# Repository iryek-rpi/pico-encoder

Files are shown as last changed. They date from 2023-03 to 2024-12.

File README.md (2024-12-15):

# TCP/IP packet encoder based on Raspberry Pi Pico W + W5500-EVB-Pico

* Raspberry Pi Pico W for serving a device configuration web page
* W5500-EVB-Pico from Wiznet for TCP/IP relay

## Sponsorship from PCBWay

* [PCBWay](https://www.pcbway.com/) kindly provided PCB of this device. This is my first time using the company's service.
* My honest impression is that their service is **well-streamlined with web-based ordering process** with good support of **instant chat assistance**. I could quickly make my order on the comprehensive web page.
* It took about a week to receive the assembled PCB at home in Korea. It was good to see that **each PCB was separately packaged**. The quality of the final product was excellent.
* I want to thank PCBWay again for their support. Highly recommend PCBWay. Try their excellent service at https://www.pcbway.com/ .

### Package arrived!
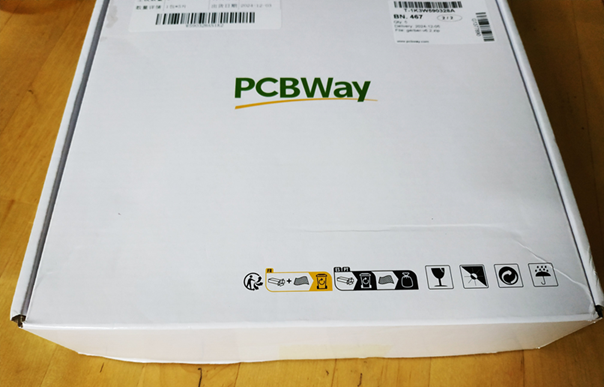
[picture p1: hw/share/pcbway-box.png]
  * 
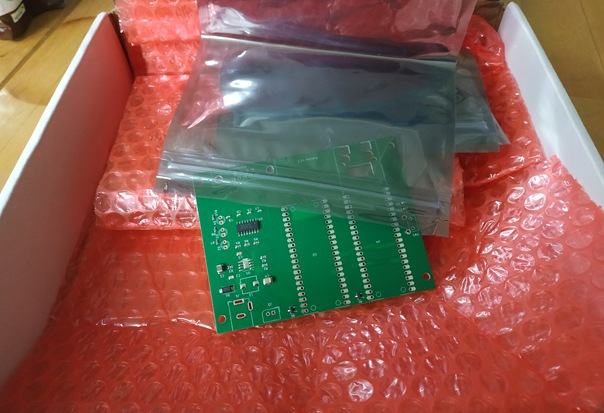
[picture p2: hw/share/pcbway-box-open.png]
  * 
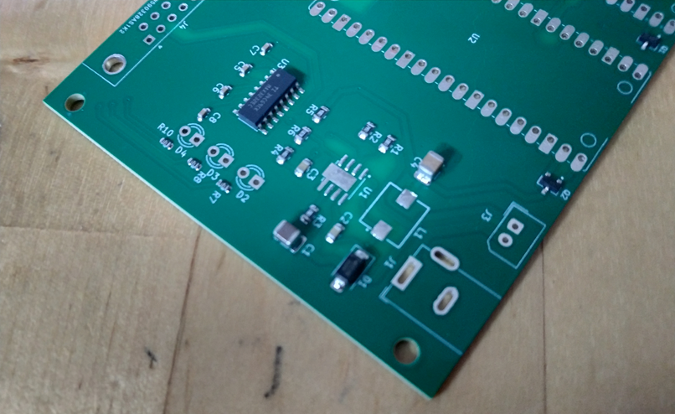
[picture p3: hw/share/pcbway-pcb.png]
  * 

### KiCad schematics & pcb
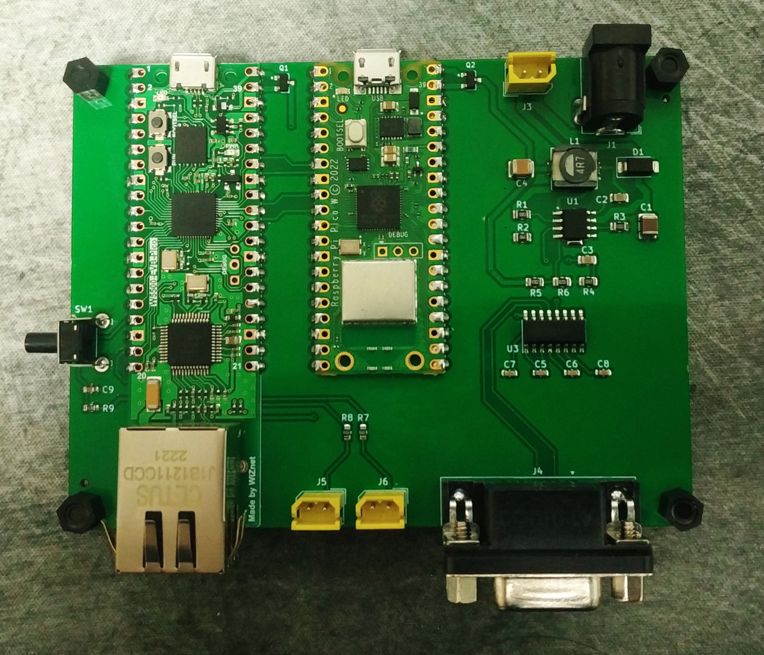
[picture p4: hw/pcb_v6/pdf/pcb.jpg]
  * 
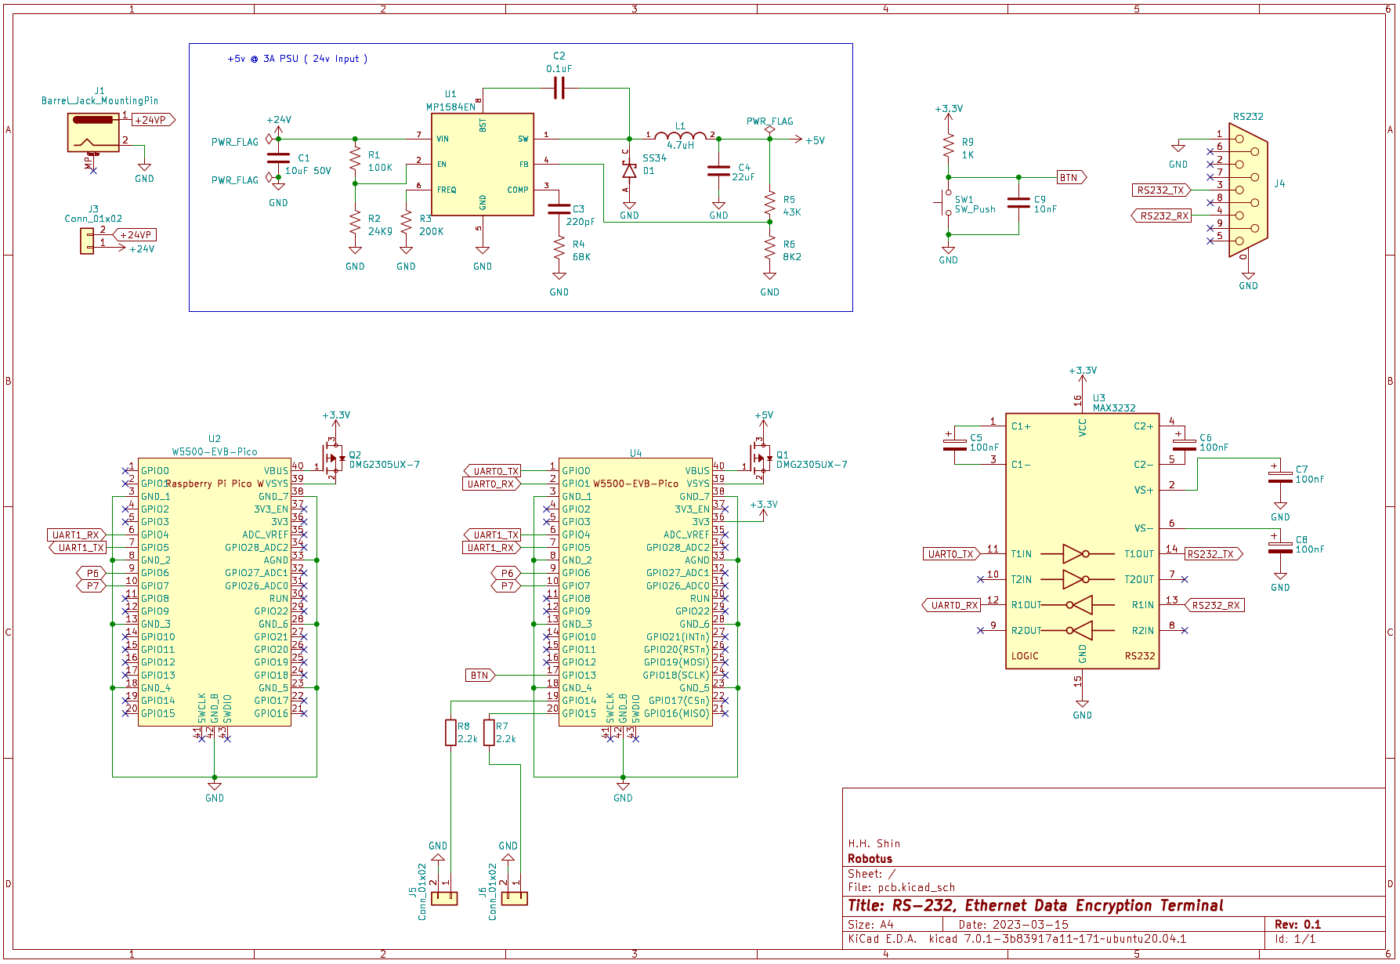
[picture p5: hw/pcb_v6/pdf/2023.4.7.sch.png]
schematics
  * 
### FreeCAD design & enclosure
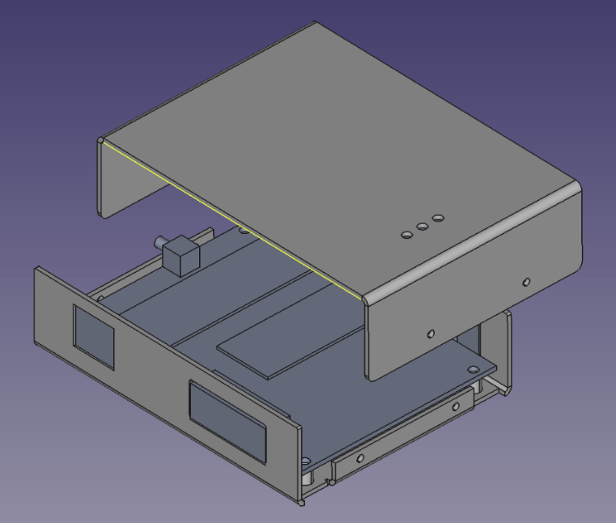
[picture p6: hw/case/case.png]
feecad design
  * 
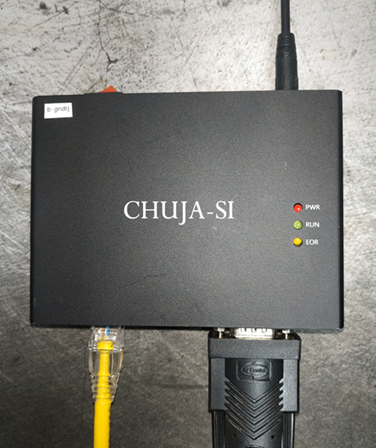
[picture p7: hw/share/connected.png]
  * 
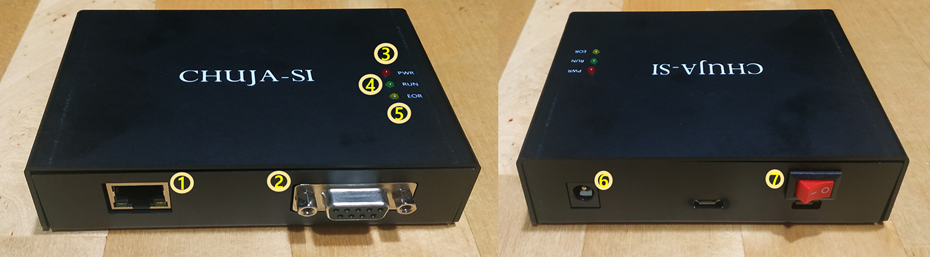
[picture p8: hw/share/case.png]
  *

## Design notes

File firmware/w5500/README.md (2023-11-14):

## MicroPython.org
* https://micropython.org/download/W5500_EVB_PICO/
* W5500_EVB_PICO-20230426-v1.20.0.uf2

## Wiznet
* 
* W5500_EVB_PICO_Hardwired_2023.10.12_Wiznet.uf2
  * MicroPython의 firmware에 Wiznet stack 올린 파일
  * https://github.com/wiznetmaker/Hard_wired_WIZNET5K-Micropython/tree/main/firmware
  * https://forum.wiznet.io/t/topic/11759/2
  * Error at asyncio stream
```
 ----WIZNET5K_PROVIDED_STACK----
Waiting for Link...
Waiting for Link...
Waiting for Link...
IP assigned:  192.168.2.8
run_forever
Task exception wasn't retrieved
future: <Task> coro= <generator object 'start_server' at 2000c440>
Traceback (most recent call last):
  File "asyncio/core.py", line 1, in run_until_complete
  File "asyncio/stream.py", line 1, in start_server
OSError: [Errno 107] ENOTCONN
Task exception wasn't retrieved
future: <Task> coro= <generator object 'start_server' at 2000c490>
Traceback (most recent call last):
  File "asyncio/core.py", line 1, in run_until_complete
  File "asyncio/stream.py", line 1, in start_server
OSError: [Errno 107] ENOTCONN
>>> 
Connection lost -- device reports readiness to read but returned no data (device disconnected or multiple access on port?)

Use Stop/Restart to reconnect.

Process ended with exit code 1.
```

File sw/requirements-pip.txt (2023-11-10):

customtkinter==5.2.1
darkdetect==0.8.0
packaging @ file:///home/conda/feedstock_root/build_artifacts/packaging_1696202382185/work
pycryptodomex @ file:///home/conda/feedstock_root/build_artifacts/pycryptodomex_1695468893816/work
pyserial @ file:///home/conda/feedstock_root/build_artifacts/pyserial_1606128640882/work
setuptools==68.2.2
wheel==0.41.3

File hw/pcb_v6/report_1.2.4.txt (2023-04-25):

Info: Front (top side) placement file: '/home/hwan/2023-work/winners/작업물/v3/pcb_v3/pcb-top-pos.csv'.
Info: Component count: 24.
Info: Back (bottom side) placement file: '/home/hwan/2023-work/winners/작업물/v3/pcb_v3/pcb-bottom-pos.csv'.
Info: Component count: 0.
Info: Full component count: 24.
Info: File generation successful.
Info: Front (top side) placement file: '/home/hwan/2023-work/winners/작업물/v3/pcb_v3/pcb-top-pos.csv'.
Info: Component count: 24.
Info: Back (bottom side) placement file: '/home/hwan/2023-work/winners/작업물/v3/pcb_v3/pcb-bottom-pos.csv'.
Info: Component count: 0.
Info: Full component count: 24.
Info: File generation successful.

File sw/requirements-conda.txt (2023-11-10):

# This file may be used to create an environment using:
# $ conda create --name <env> --file <this file>
# platform: linux-64
_libgcc_mutex=0.1=conda_forge
_openmp_mutex=4.5=2_gnu
bzip2=1.0.8=hd590300_5
ca-certificates=2023.7.22=hbcca054_0
customtkinter=5.2.1=pypi_0
darkdetect=0.8.0=pypi_0
gmp=6.2.1=h58526e2_0
ld_impl_linux-64=2.40=h41732ed_0
libexpat=2.5.0=hcb278e6_1
libffi=3.4.2=h7f98852_5
libgcc-ng=13.2.0=h807b86a_2
libgomp=13.2.0=h807b86a_2
libnsl=2.0.1=hd590300_0
libsqlite=3.44.0=h2797004_0
libstdcxx-ng=13.2.0=h7e041cc_2
libuuid=2.38.1=h0b41bf4_0
libzlib=1.2.13=hd590300_5
ncurses=6.4=h59595ed_2
openssl=3.1.4=hd590300_0
packaging=23.2=pyhd8ed1ab_0
pip=23.3.1=pyhd8ed1ab_0
pycryptodomex=3.19.0=py312h98912ed_1
pyserial=3.5=pyhd8ed1ab_0
python=3.12.0=hab00c5b_0_cpython
python_abi=3.12=4_cp312
readline=8.2=h8228510_1
setuptools=68.2.2=pyhd8ed1ab_0
tk=8.6.13=noxft_h4845f30_101
tzdata=2023c=h71feb2d_0
wheel=0.41.3=pyhd8ed1ab_0
xz=5.2.6=h166bdaf_0

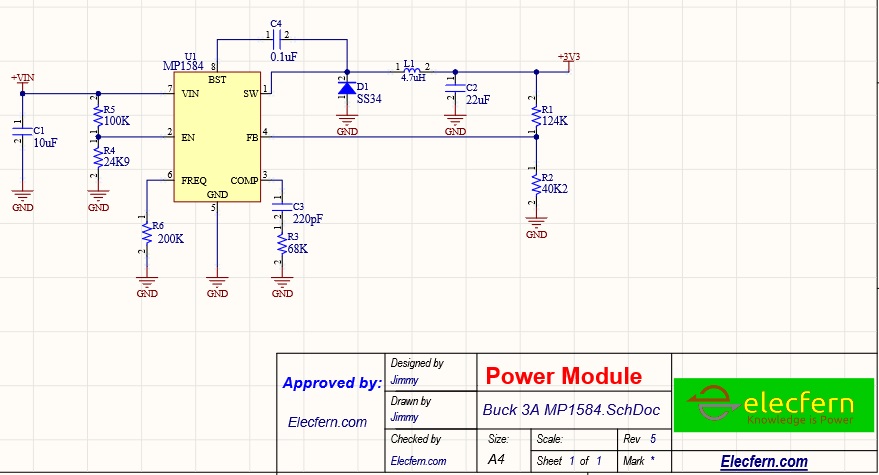
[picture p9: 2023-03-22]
hw/parts/MP1584EN_Switching-Regulator/MP1584EN-DC-DC-Buck-Converter-Power-Module/image/MP1584EN DC-DC Buck Converter Power Module-Schematic-Elecfern.JPG

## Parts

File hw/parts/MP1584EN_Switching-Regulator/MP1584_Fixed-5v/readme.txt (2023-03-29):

https://oshwlab.com/aikopras/power-supply-mp1584

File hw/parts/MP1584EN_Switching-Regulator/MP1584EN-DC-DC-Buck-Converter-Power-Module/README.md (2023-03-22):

**1.	Specifications**

- Dimension: 21×21mm.
- Input voltage: 4.5V÷28V.
- Fixed out voltage: 3.3V (You can adjust the voltage by changing feedback resistors).
- Current output: 3A.

enter image title here

Figure 1: Dimension of board

**2.	Notations**
- +VIN: Input voltage.
- GND: Common Ground for input and output voltage.
- +3V3: Output voltage.

**3.	Schematic Design**

enter image title here

Figure 2: Operating principle of relay module

**4.	3D model**

Some images are about this board you can see at **https://youtu.be/jVNwZ8kD4Sc**
enter image title here

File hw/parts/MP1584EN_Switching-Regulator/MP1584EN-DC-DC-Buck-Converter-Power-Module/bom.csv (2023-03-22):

Line # | Designator | Name | Description | Quantity | Manufacturer 1 | Manufacturer Part Number 1 | Link
1 | C1 | 10uF | 10µF ±20% 50V Ceramic Capacitor X5R 1210 (3225 Metric) | 1 | Taiyo Yuden | CEUMK325BJ106MM-T | https://amzn.to/3akMjF3
2 | C2 | 22uF | 22µF ±10% 25V Ceramic Capacitor X5R 1210 (3225 Metric) | 1 | KEMET | C1210C226K3PACTU | https://amzn.to/33zMOs9
3 | C3 | 220pF | 220pF ±10% 100V Ceramic Capacitor BX 0805 (2012 Metric) | 1 | KEMET | CDR01BX221BKUS7185 | https://amzn.to/2WzREnE
4 | C4 | 0.1uF | 0.1uF 50V | 1 | KEMET | C0805C104K5RACTU | https://amzn.to/3aUmz24
5 | D1 | SS34 | 3A 40V SS34 SMA | 1 | Multicomp | SS34A | https://amzn.to/2QbmNd4
6 | L1 | 4.7uH | RLF7030T-4R7 4.7µH Shielded Wirewound Inductor 3.4A 31.2 mOhm Max Nonstandard | 1 | TDK | RLF7030T-4R7M3R4 | https://www.ebay.com/itm/Drossel-Ferrit-SMD-4-7uH-3-4A-26m-20-Serie-RLF-RLF7030T-4R7M3R4-SMD-Leistun/383158359568
7 | R1 | 124K | 124 kOhms ±1% 0.125W, 1/8W Chip Resistor 0805 (2012 Metric) Moisture Resistant Thick Film | 1 | Yageo | RC0805FR-07124KL | https://www.ebay.com/itm/Qty-100-124K-ohm-1-1-8W-0805-thick-film-resistors/192867371274
8 | R2 | 40K2 | 40.2 kOhms ±1% 0.125W, 1/8W Chip Resistor 0805 (2012 Metric) Automotive AEC-Q200 Thick Film | 1 | Stackpole Electronics | RMCF0805FT40K2 | https://www.ebay.com/itm/50PCS-1-8W-0805-SMD-SMT-Resistors-1-Full-Range-of-Values-0-1-to-20M/253771062996
9 | R3 | 68K | 4.7 kOhms ±1% 0.125W, 1/8W Chip Resistor 0805 (2012 Metric) Automotive AEC-Q200 Thick Film | 1 | Vishay | CRCW0805680KFKEA | https://amzn.to/3dlf6uH
10 | R4 | 24K9 | 200 Ohms ±5% 0.125W, 1/8W Chip Resistor 0805 (2012 Metric) Automotive AEC-Q200 Thick Film | 1 | Yageo | RC0805FR-0724K9L | https://www.ebay.com/itm/50PCS-1-8W-0805-SMD-SMT-Resistors-1-Full-Range-of-Values-0-1-to-20M/253771062996
11 | R5 | 100K | 100 kOhms ±1% 0.125W, 1/8W Chip Resistor 0805 (2012 Metric) Moisture Resistant Thick Film | 1 | Yageo | RC0805FR-07100KL | https://amzn.to/3dlf6uH
12 | R6 | 200K | 200 kOhms ±5% 0.125W, 1/8W Chip Resistor 0805 (2012 Metric) Automotive AEC-Q200 Thick Film | 1 | Stackpole Electronics | RMCF0805JT200K | https://amzn.to/2U7vtn3
13 | U1 | MP1584 | Buck Switching Regulator IC Positive Adjustable 0.8V 1 Output 3A 8-SOIC (0.154", 3.90mm Width) Exposed Pad | 1 | Monolithic Power Systems | MP1584EN-LF-Z | https://amzn.to/2JasvYF
14 | Wire |  |  | 1 |  |  | https://amzn.to/3d96tUf

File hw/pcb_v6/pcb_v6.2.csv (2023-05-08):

Comment | Designator | Footprint | LCSC
10uF 50V | C1 | Capacitor_SMD:C_1210_3225Metric | C576234
0.1uF | C2 | Capacitor_SMD:C_0805_2012Metric | C49678
220pF | C3 | Capacitor_SMD:C_0805_2012Metric | C107145
22uF | C4 | Capacitor_SMD:C_1210_3225Metric | C309062
100nF | C5,C6,C7,C8 | Capacitor_SMD:C_0603_1608Metric | C14663
10nF | C9 | Capacitor_SMD:C_0603_1608Metric | C57112
SS34 | D1 | Diode_SMD:D_SMA | C8678
LED | D2,D3,D4 | LED_THT:LED_D3.0mm
Barrel_Jack_MountingPin | J1 | Connector_BarrelJack:BarrelJack_GCT_DCJ200-10-A_Horizontal
Conn_01x02 | J3 | Connector_Molex:Molex_SPOX_5267-02A_1x02_P2.50mm_Vertical
RS232 | J4 | Connector_Dsub:DSUB-9_Female_Horizontal_P2.77x2.84mm_EdgePinOffset7.70mm_Housed_MountingHolesOffset9.12mm
4.7uH | L1 | 0.winners:INDP7368X320_Inductor
DMG2305UX-7 | Q1,Q2 | 0.winners:SOT91P240X110-3N_DMG2305UX-7 | C150470
100K | R1 | Resistor_SMD:R_0805_2012Metric | C149504
24K9 | R2 | Resistor_SMD:R_0805_2012Metric | C422846
200K | R3 | Resistor_SMD:R_0805_2012Metric | C17539
68K | R4 | Resistor_SMD:R_0805_2012Metric | C17801
43K | R5 | Resistor_SMD:R_0805_2012Metric | C17695
8K2 | R6 | Resistor_SMD:R_0805_2012Metric | C17828
120 | R7,R8,R10 | Resistor_SMD:R_0603_1608Metric | C22787
1K | R9 | Resistor_SMD:R_0603_1608Metric | C21190
SW_Push | SW1 | Button_Switch_THT:SW_SPST_Omron_B3F-315x_Angled
MP1584EN | U1 | 0.winners:SOIC127P600X170-9N_MP1584EN
Raspberry Pi Pico W | U2 | 0.winners:Raspberry_Pi_Pico_W_SMT_THT
MAX3232 | U3 | Package_SO:SO-16_3.9x9.9mm_P1.27mm | C354115
W5500-EVB-Pico | U4 | 0.winners:W5500-EVB-Pico_SMT_THT

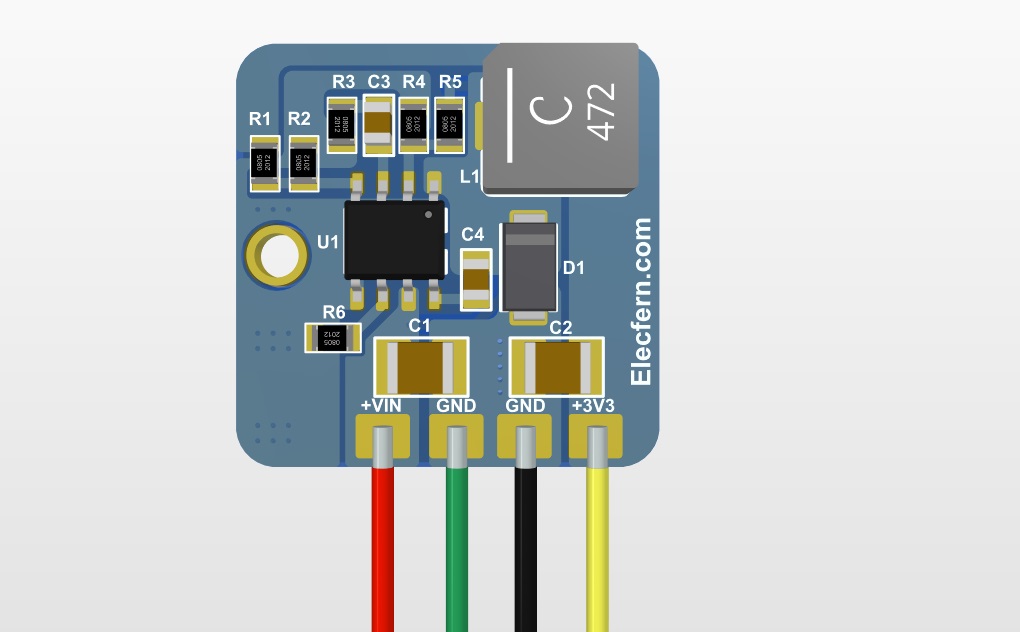
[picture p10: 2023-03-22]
hw/parts/MP1584EN_Switching-Regulator/MP1584EN-DC-DC-Buck-Converter-Power-Module/image/MP1584EN DC-DC Buck Converter Power Module-3D-Elecfern.JPG

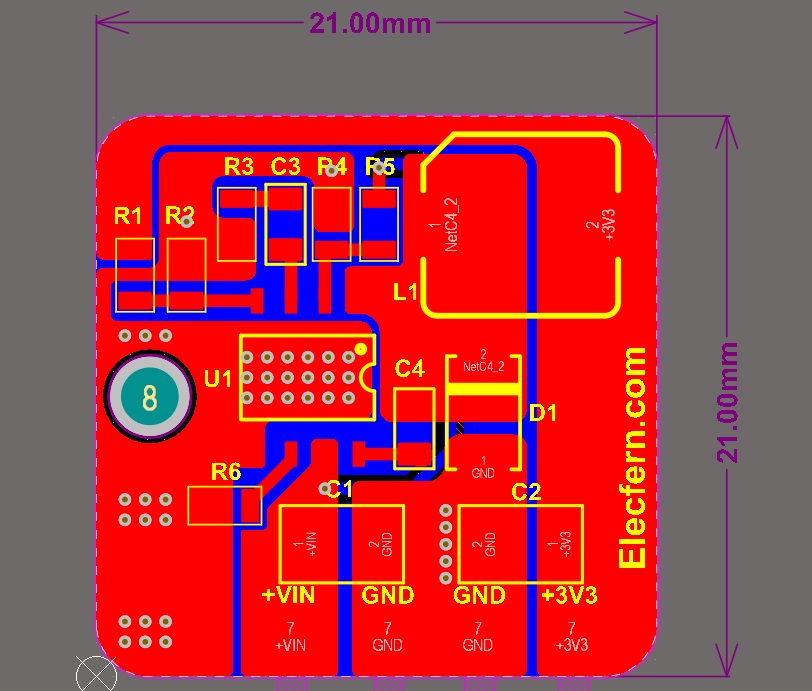
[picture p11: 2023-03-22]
hw/parts/MP1584EN_Switching-Regulator/MP1584EN-DC-DC-Buck-Converter-Power-Module/image/MP1584EN DC-DC Buck Converter Power Module-Dimension-Elecfern.JPG

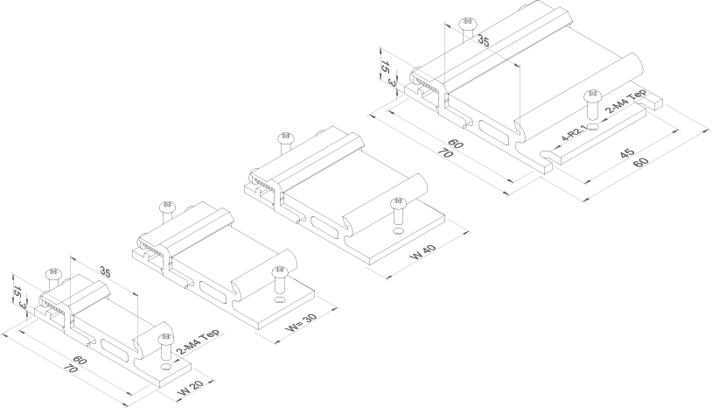
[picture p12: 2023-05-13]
hw/parts/Din-Rail-Bracket-DRB35-70-30/DRB35-70-30.png

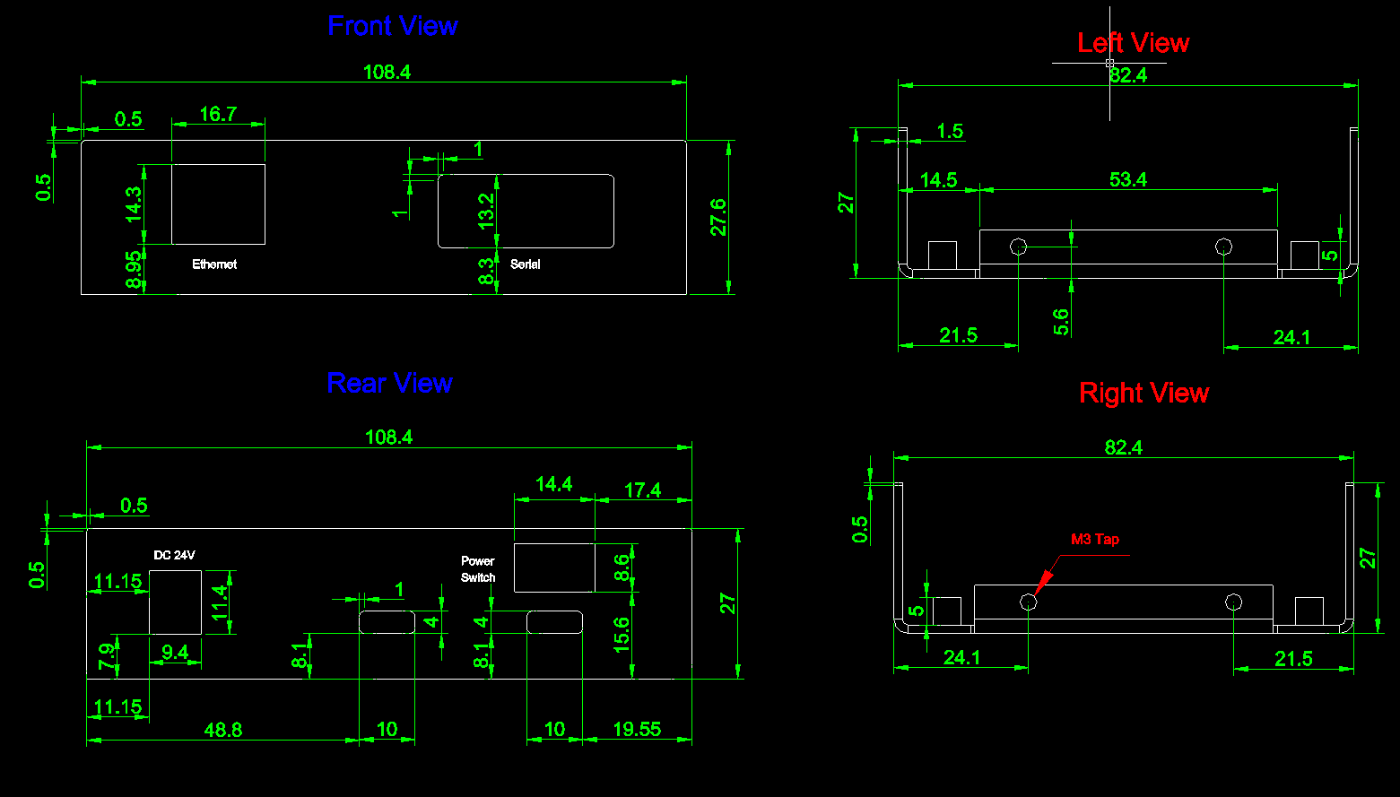
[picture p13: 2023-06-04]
hw/case/2023.5.26_order/2023.5.30_케이스_상하판/하판1.png

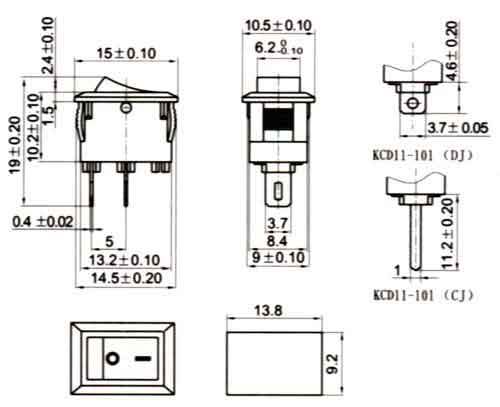
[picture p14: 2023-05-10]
hw/parts/rocker-sw-10x15/rocker_sw_10x15.jpg

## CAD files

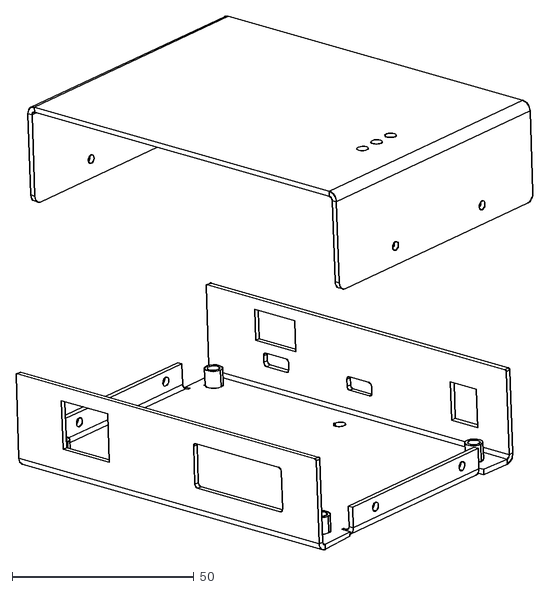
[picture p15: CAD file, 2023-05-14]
hw/case/case-v2/dxf/whole.dxf
142.2 x 146.9

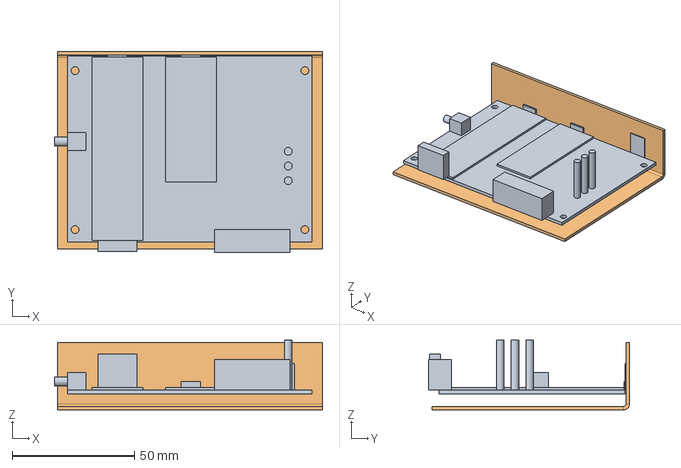
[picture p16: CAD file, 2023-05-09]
hw/case/case-v2-backup/winners-case-v2.FCStd
109.6 x 82.4 x 28.6 mm
base-sheet

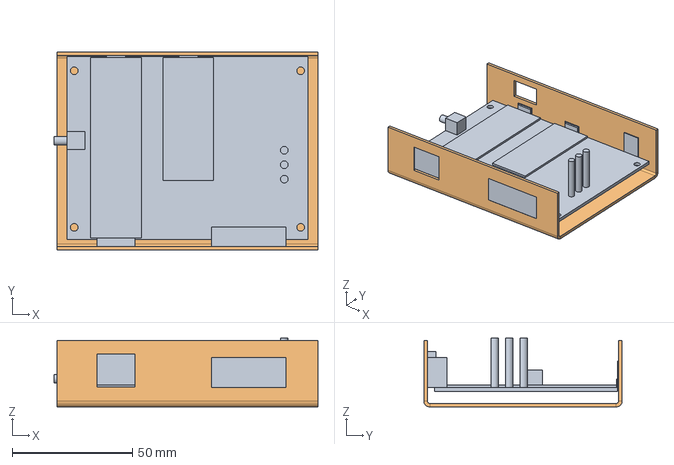
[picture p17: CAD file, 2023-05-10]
hw/case/case-v2-backup2/winners-case-v2.1.FCStd
109.6 x 82.4 x 28.6 mm
base-sheet

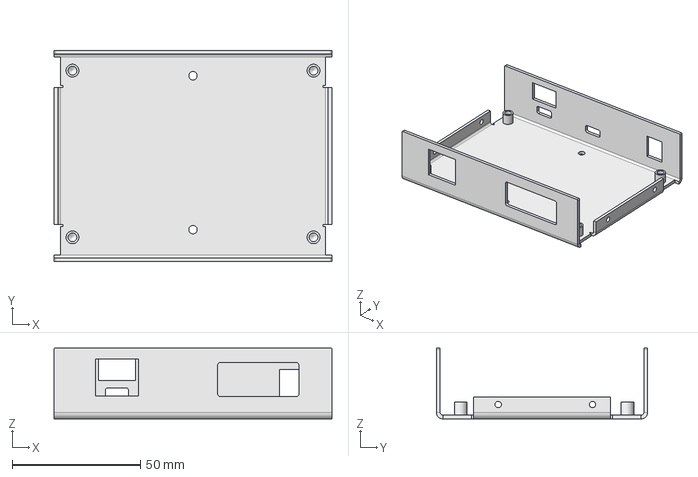
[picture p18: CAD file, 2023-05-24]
hw/case/case3d/winners-case-v2-3d.FCStd
108.4 x 82.4 x 27.6 mm

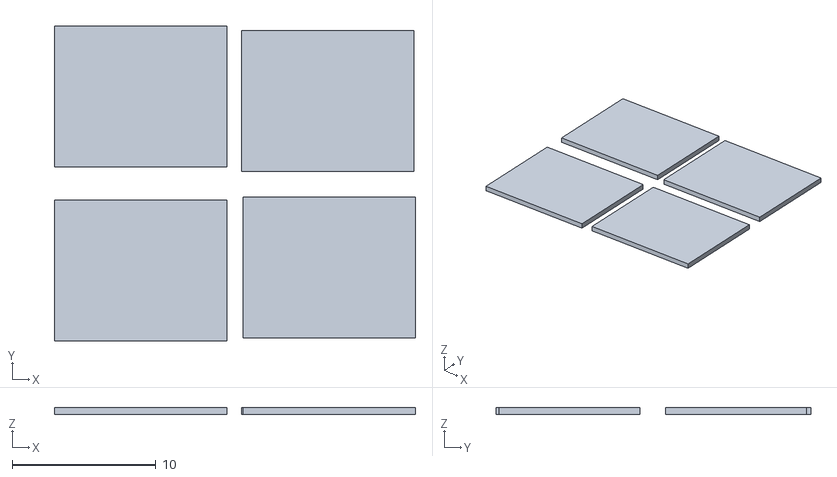
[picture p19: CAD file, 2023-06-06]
hw/case/usb_cover_4.stl
25.1 x 21.9 x 0.5

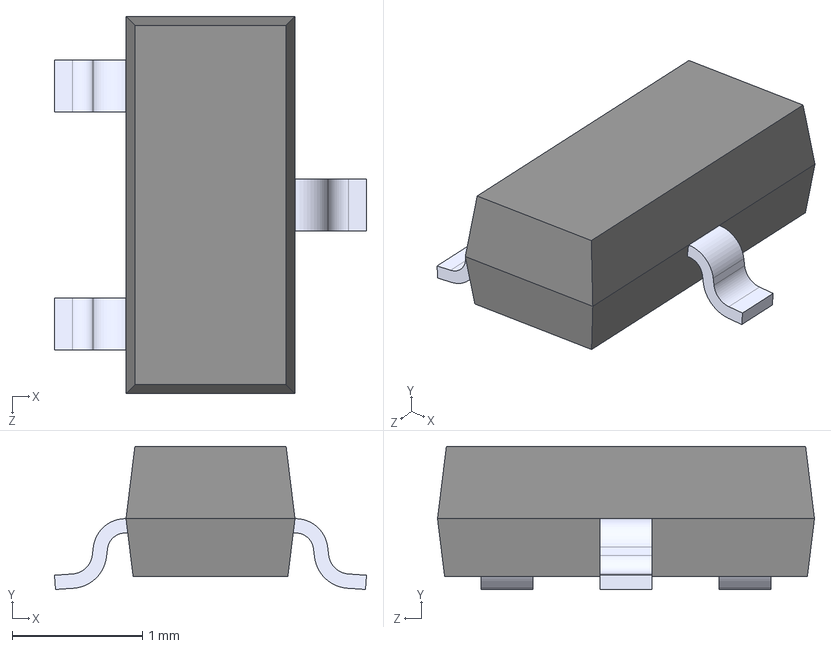
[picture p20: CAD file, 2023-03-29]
hw/parts/DMG2305UX_P-Channel_Mosfet/DMG2305UX-7/DMG2305UX-7.step
2.40 x 1.10 x 2.90 mm

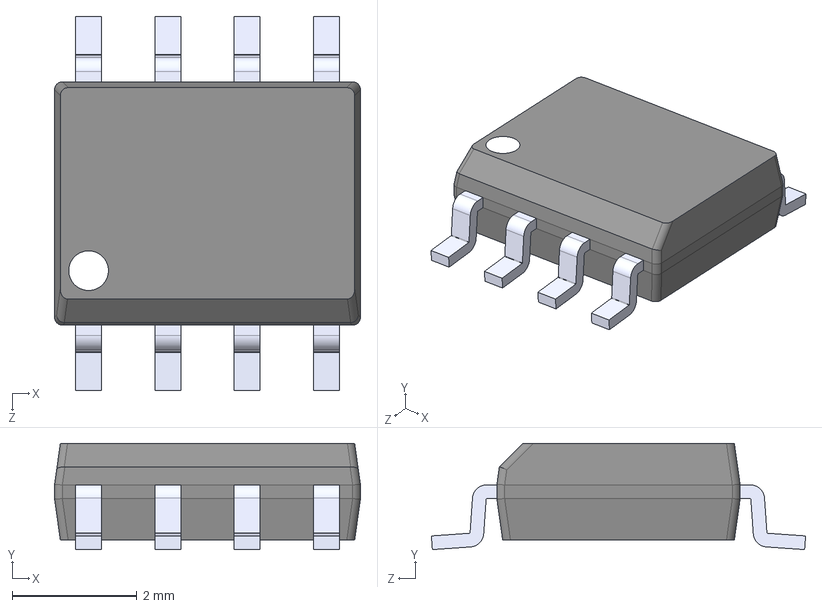
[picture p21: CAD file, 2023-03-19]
hw/parts/MP1584EN_Switching-Regulator/MP1584EN-KiCAD/MP1584EN.step
4.90 x 1.70 x 5.99 mm

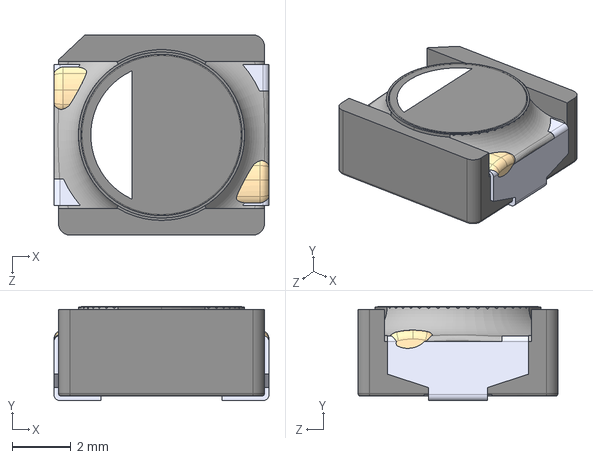
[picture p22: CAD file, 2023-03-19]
hw/parts/RLF7030T-4R7M3R4_Inductor/RLF7030T-4R7M3R4/RLF7030T-4R7M3R4.step
7.30 x 3.20 x 6.80 mm

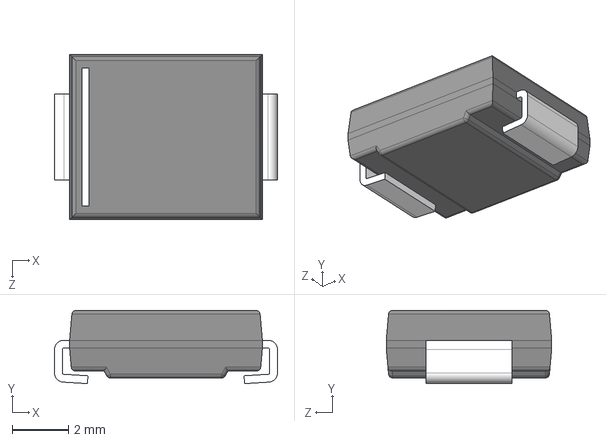
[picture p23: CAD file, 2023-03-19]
hw/parts/SS34_Schottky-Rectifier/SS34/SS34.step
7.95 x 2.61 x 5.90 mm

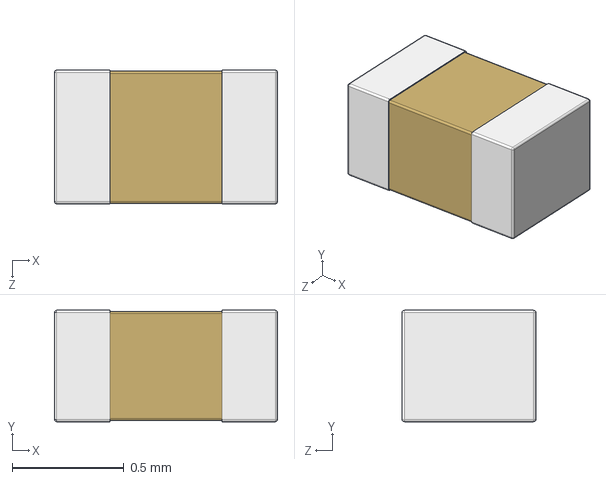
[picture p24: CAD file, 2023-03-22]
hw/parts/W5500-EVB-Pico/altium2kicad/W5500-EVB-Pico_V100-PcbDoc/Root Entry/Models/10.dat.step
1.00 x 0.5 x 0.6 mm

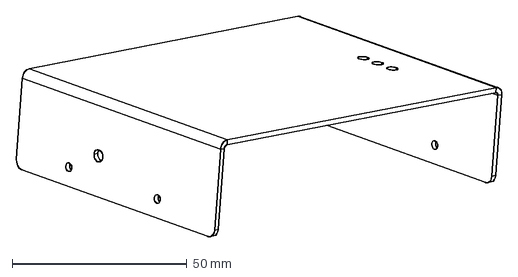
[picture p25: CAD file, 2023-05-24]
hw/case/case-v2/dxf/top_left_3d2.dxf
139.0 x 63.1 mm

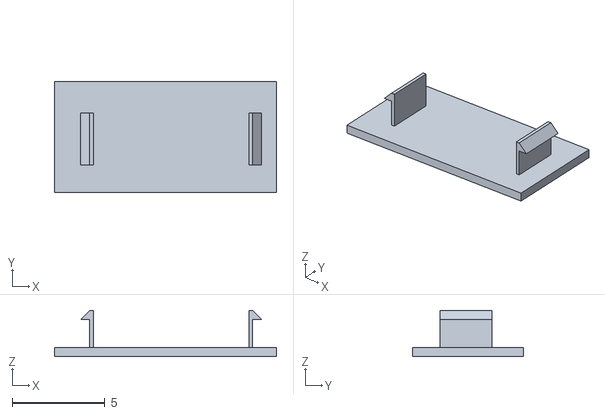
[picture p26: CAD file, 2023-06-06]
hw/case/usb_cover.stl
12.0 x 6.00 x 2.50

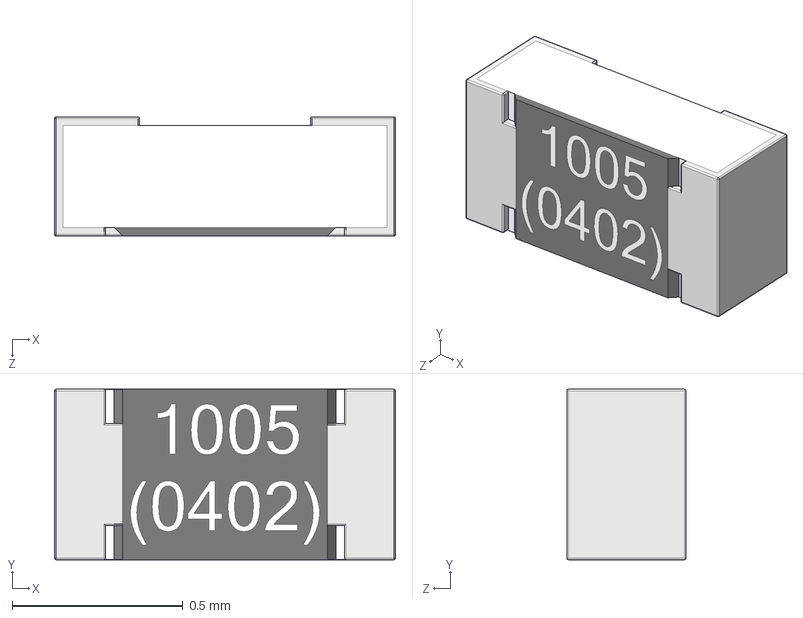
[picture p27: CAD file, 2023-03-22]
hw/parts/W5500-EVB-Pico/altium2kicad/W5500-EVB-Pico_V100-PcbDoc/Root Entry/Models/4.dat.step
1.00 x 0.5 x 0.35 mm

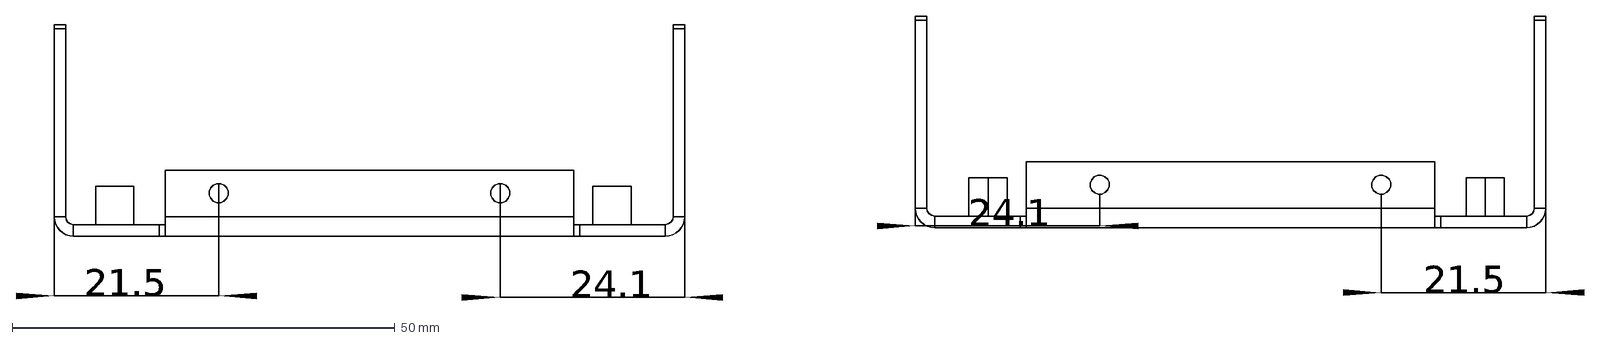
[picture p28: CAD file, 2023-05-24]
hw/case/case-v2/dxf/base_left_right.dxf
21.5
24.1

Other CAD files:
hw/case/2023.5.15_order/case_2023.5.15-1-autocad.dwg
hw/case/2023.5.26_order/2023.5.30_케이스_상하판/case_2023.5.30-1-autocad.dwg
hw/case/case-v2/dxf/case_2023.5.15-1-autocad.dwg
hw/case/case_base.stl
hw/case/case-v2/backups/winners-case-v2.FCStd
hw/case/case-v2/backups/winners-case-v2_fail_db9.FCStd
hw/case/case-v2/dxf/base.dxf
hw/case/case-v2/dxf/case_2023.5.15-1.dwg
hw/case/case-v2/dxf/left.dxf
hw/case/case-v2/dxf/right_view.dxf
hw/case/case-v2/dxf/top.dxf
hw/case/case-v2/dxf/top_left_3d.dxf
hw/case/case-v2/dxf/top_right_3d.dxf
hw/parts/W5500-EVB-Pico/altium2kicad/W5500-EVB-Pico_V100-PcbDoc/Root Entry/Models/11.dat.step
hw/parts/W5500-EVB-Pico/altium2kicad/W5500-EVB-Pico_V100-PcbDoc/Root Entry/Models/12.dat.step
hw/parts/W5500-EVB-Pico/altium2kicad/W5500-EVB-Pico_V100-PcbDoc/Root Entry/Models/14.dat.step
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

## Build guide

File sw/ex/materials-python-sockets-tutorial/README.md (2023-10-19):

# Socket Programming in Python (Guide)

This is the source code for [Socket Programming in Python (Guide)](https://realpython.com/python-sockets/).

## Requirements

- [Python](https://www.python.org/) 3.6 or later.

## License

The MIT License. See the file LICENSE in this repository's base directory.

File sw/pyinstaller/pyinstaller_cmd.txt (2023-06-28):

(1) customtkinter 위치를 확인

pip show customtkinter

(2) pyinstaller 실행

pyinstaller --noconfirm --onedir --windowed --add-data "c:\tools\miniconda3\envs\tkinter\lib\site-packages/customtkinter;customtkinter/" "c:\dev\pico-encoder\epc\kc\k2.py"

(3) kc 폴더 아래의 k2_config.txt를 pyinstaller가 생성한 dist/kc/ 에 복사

(4) /dist/kc/ 폴더를 압축

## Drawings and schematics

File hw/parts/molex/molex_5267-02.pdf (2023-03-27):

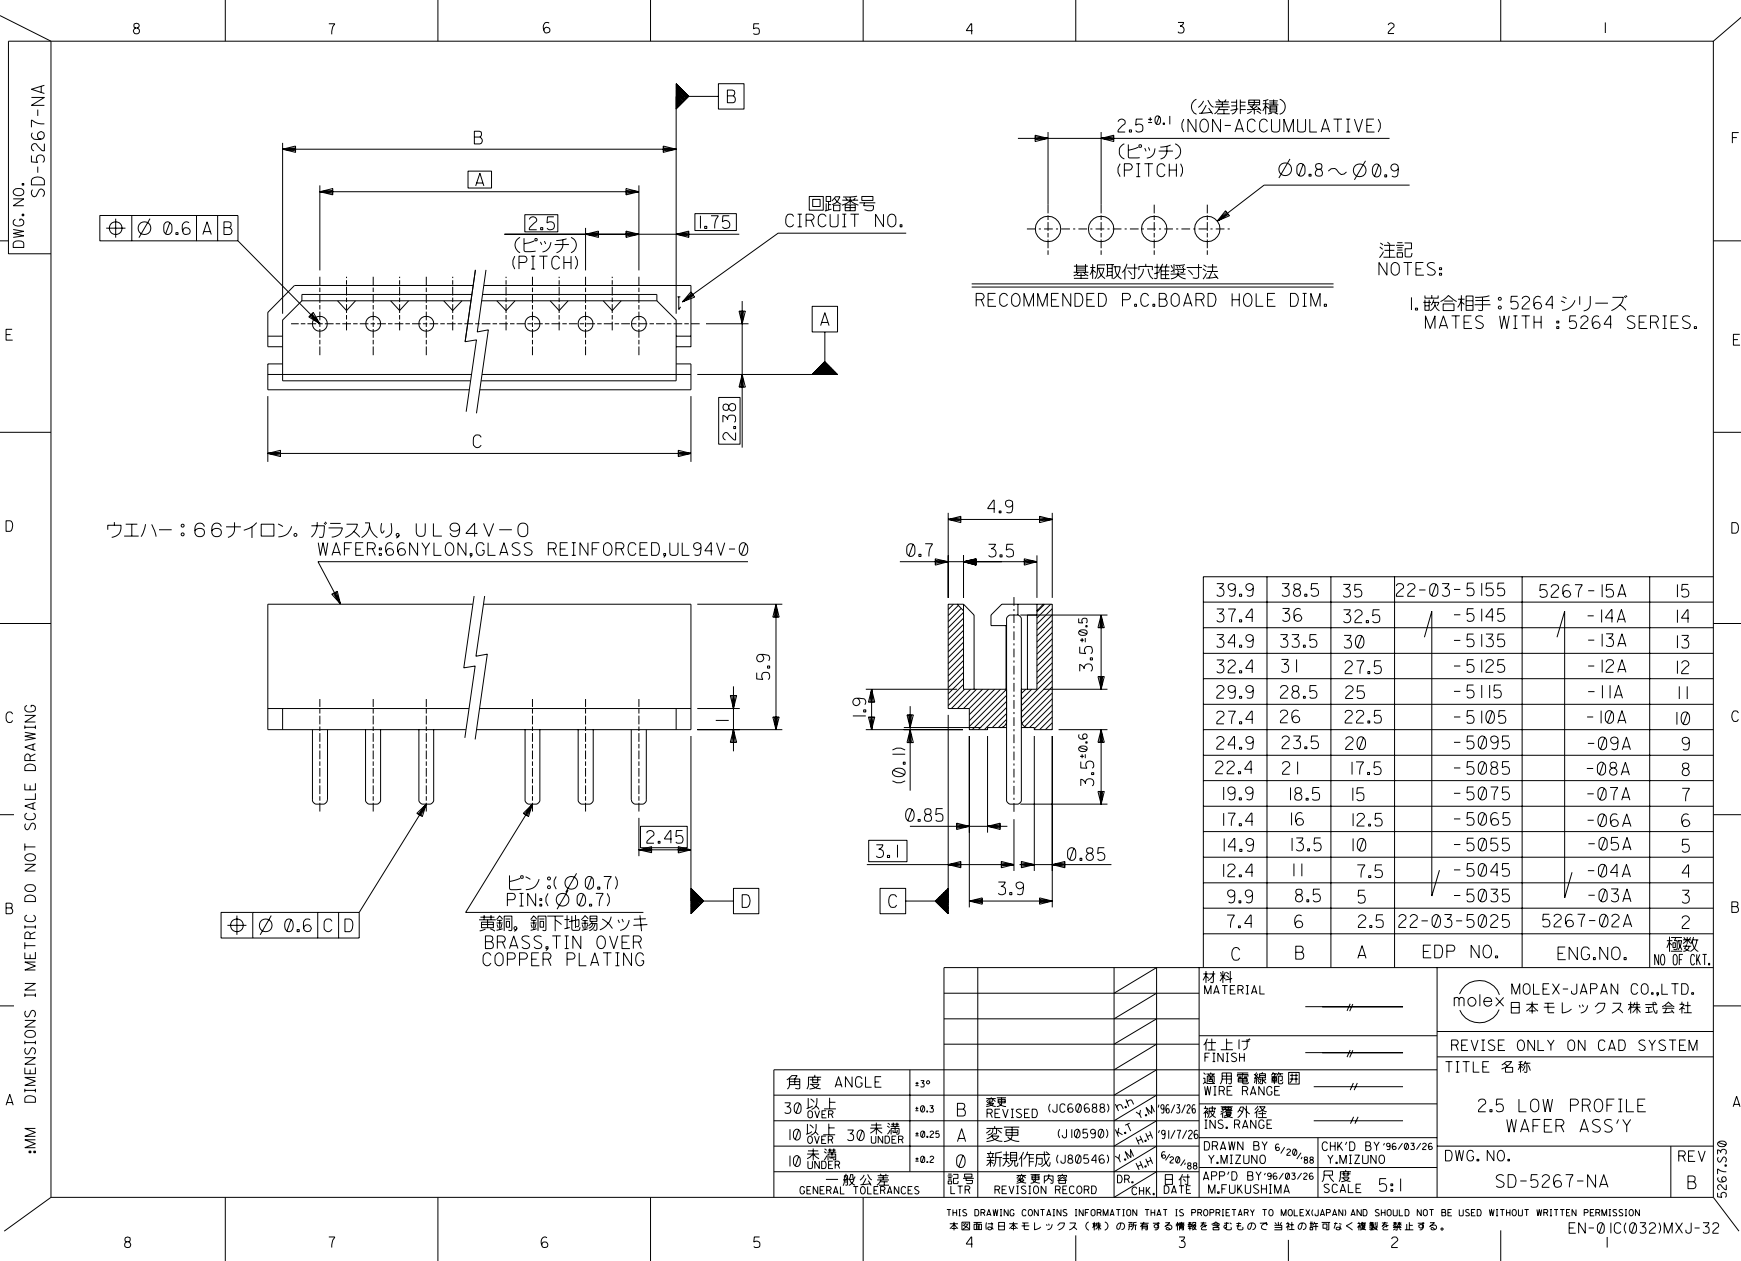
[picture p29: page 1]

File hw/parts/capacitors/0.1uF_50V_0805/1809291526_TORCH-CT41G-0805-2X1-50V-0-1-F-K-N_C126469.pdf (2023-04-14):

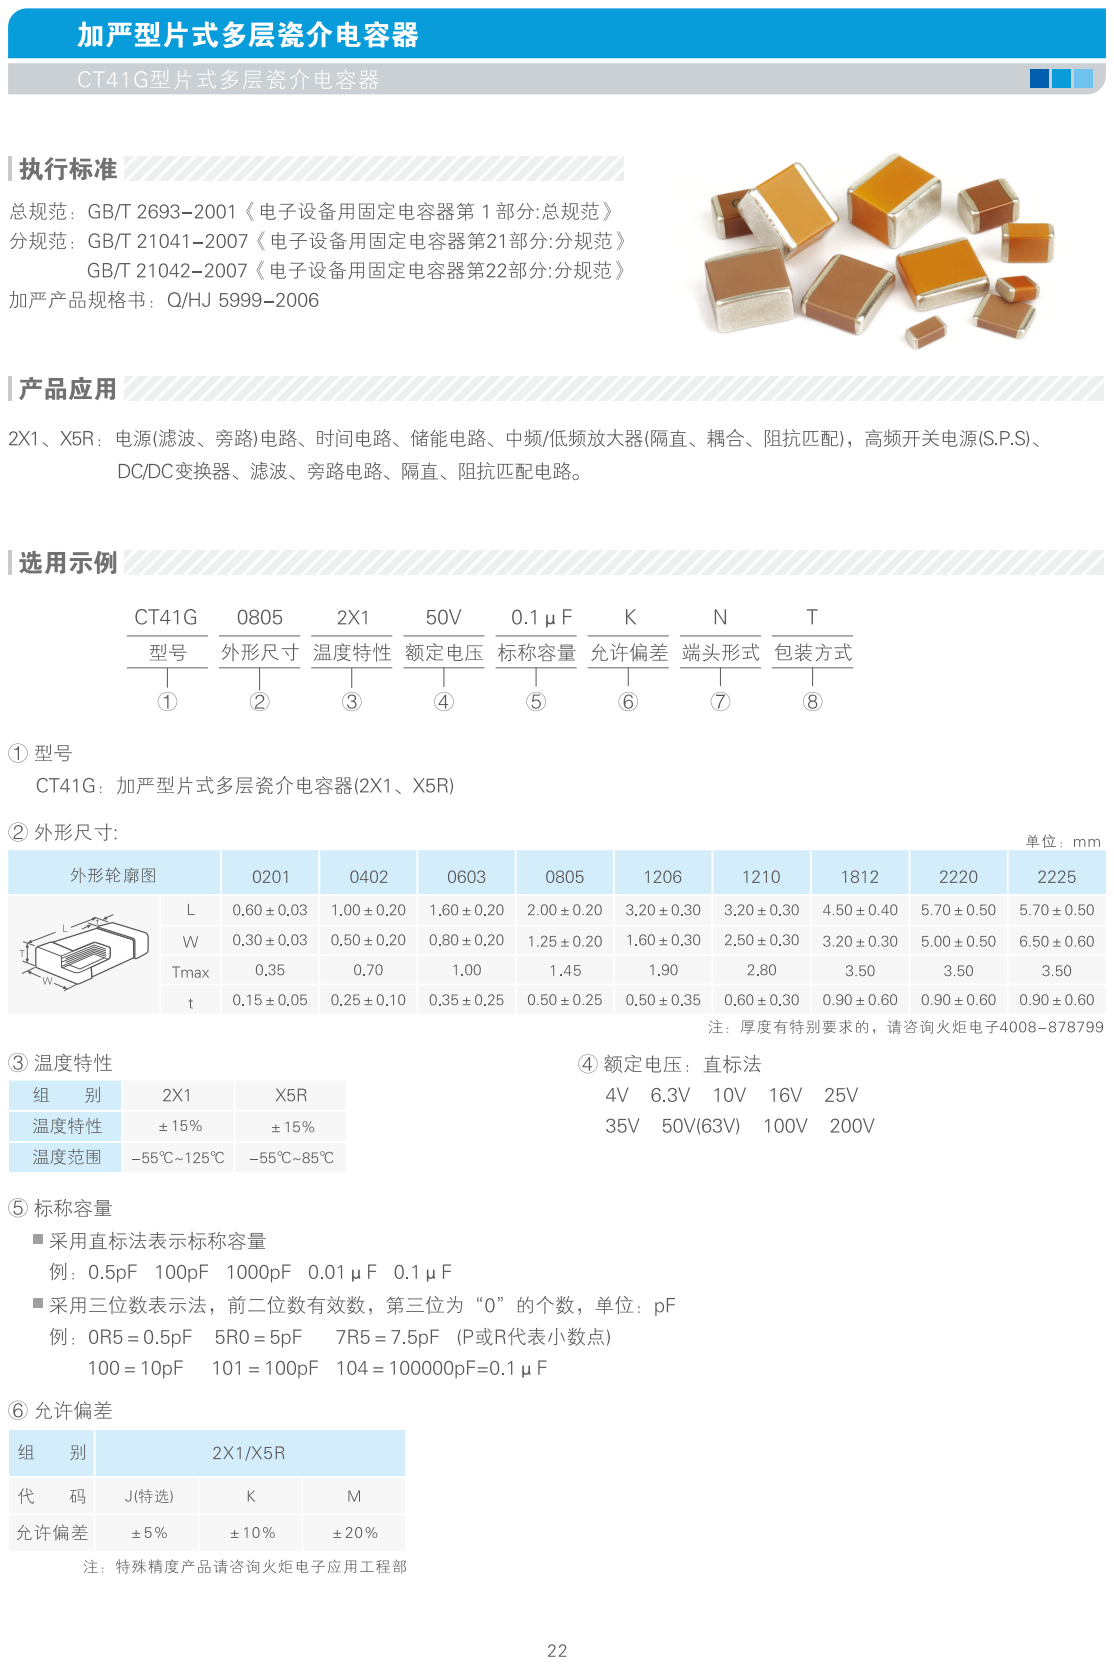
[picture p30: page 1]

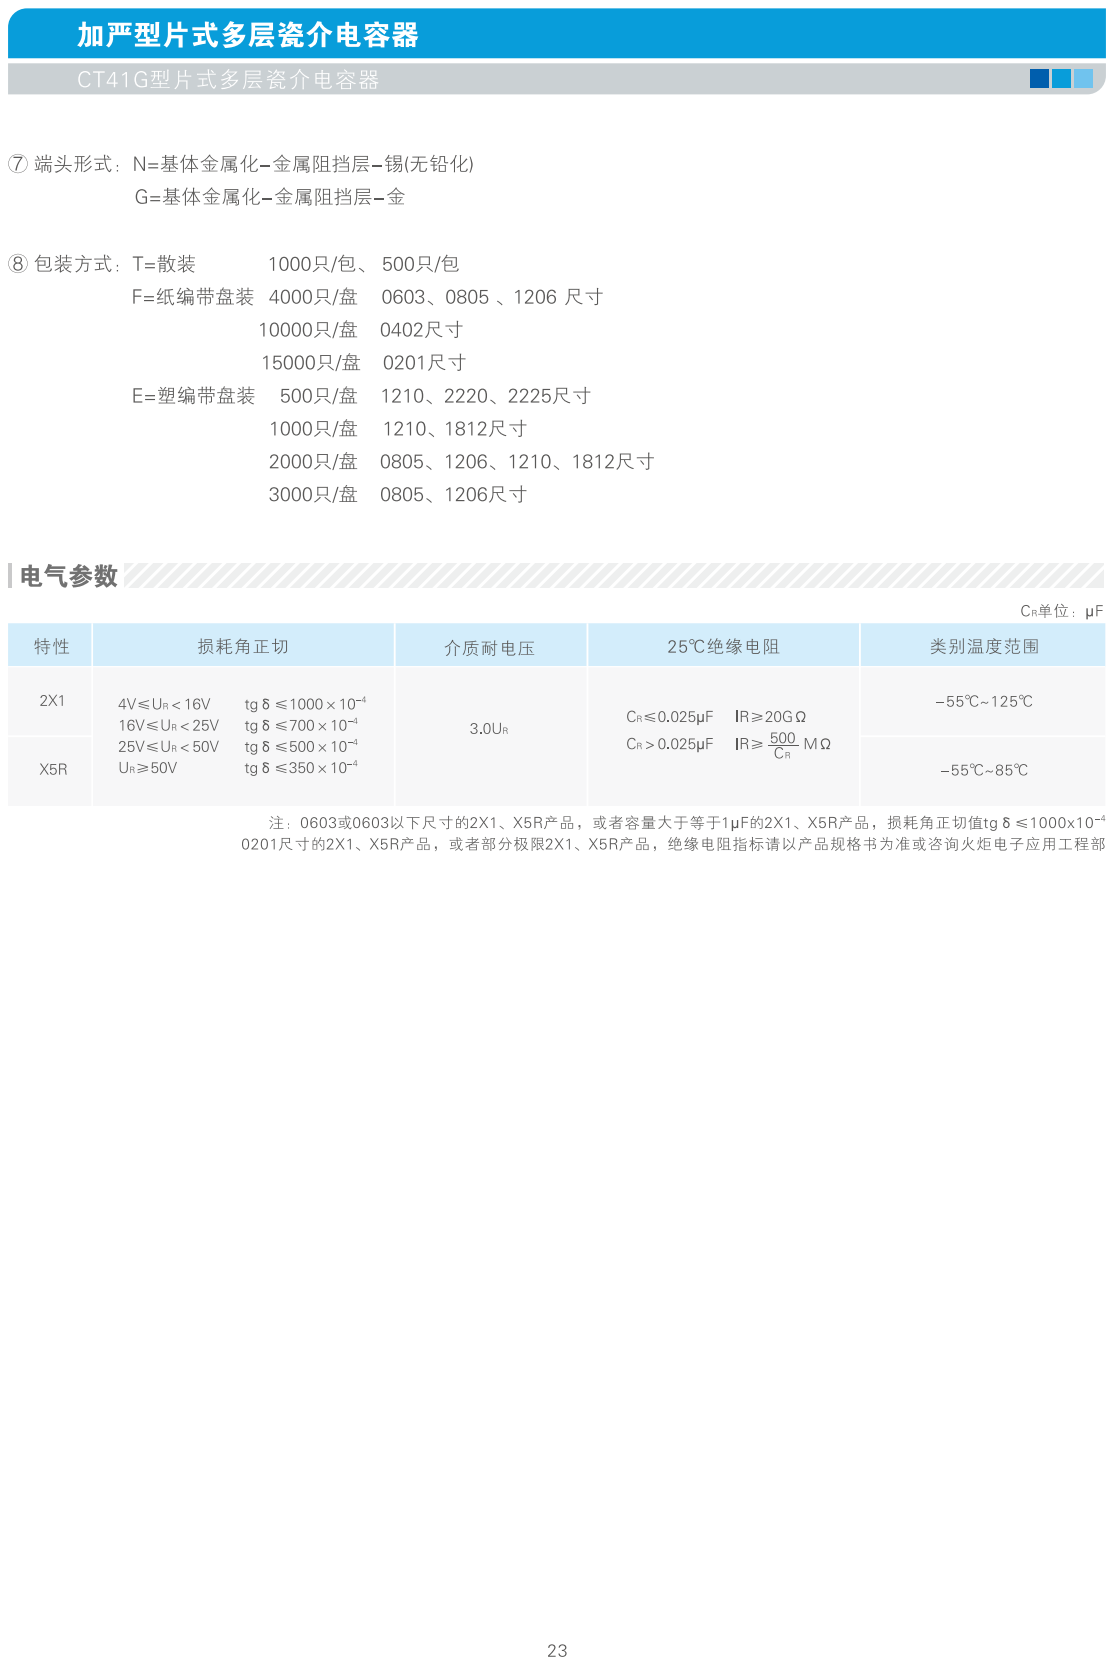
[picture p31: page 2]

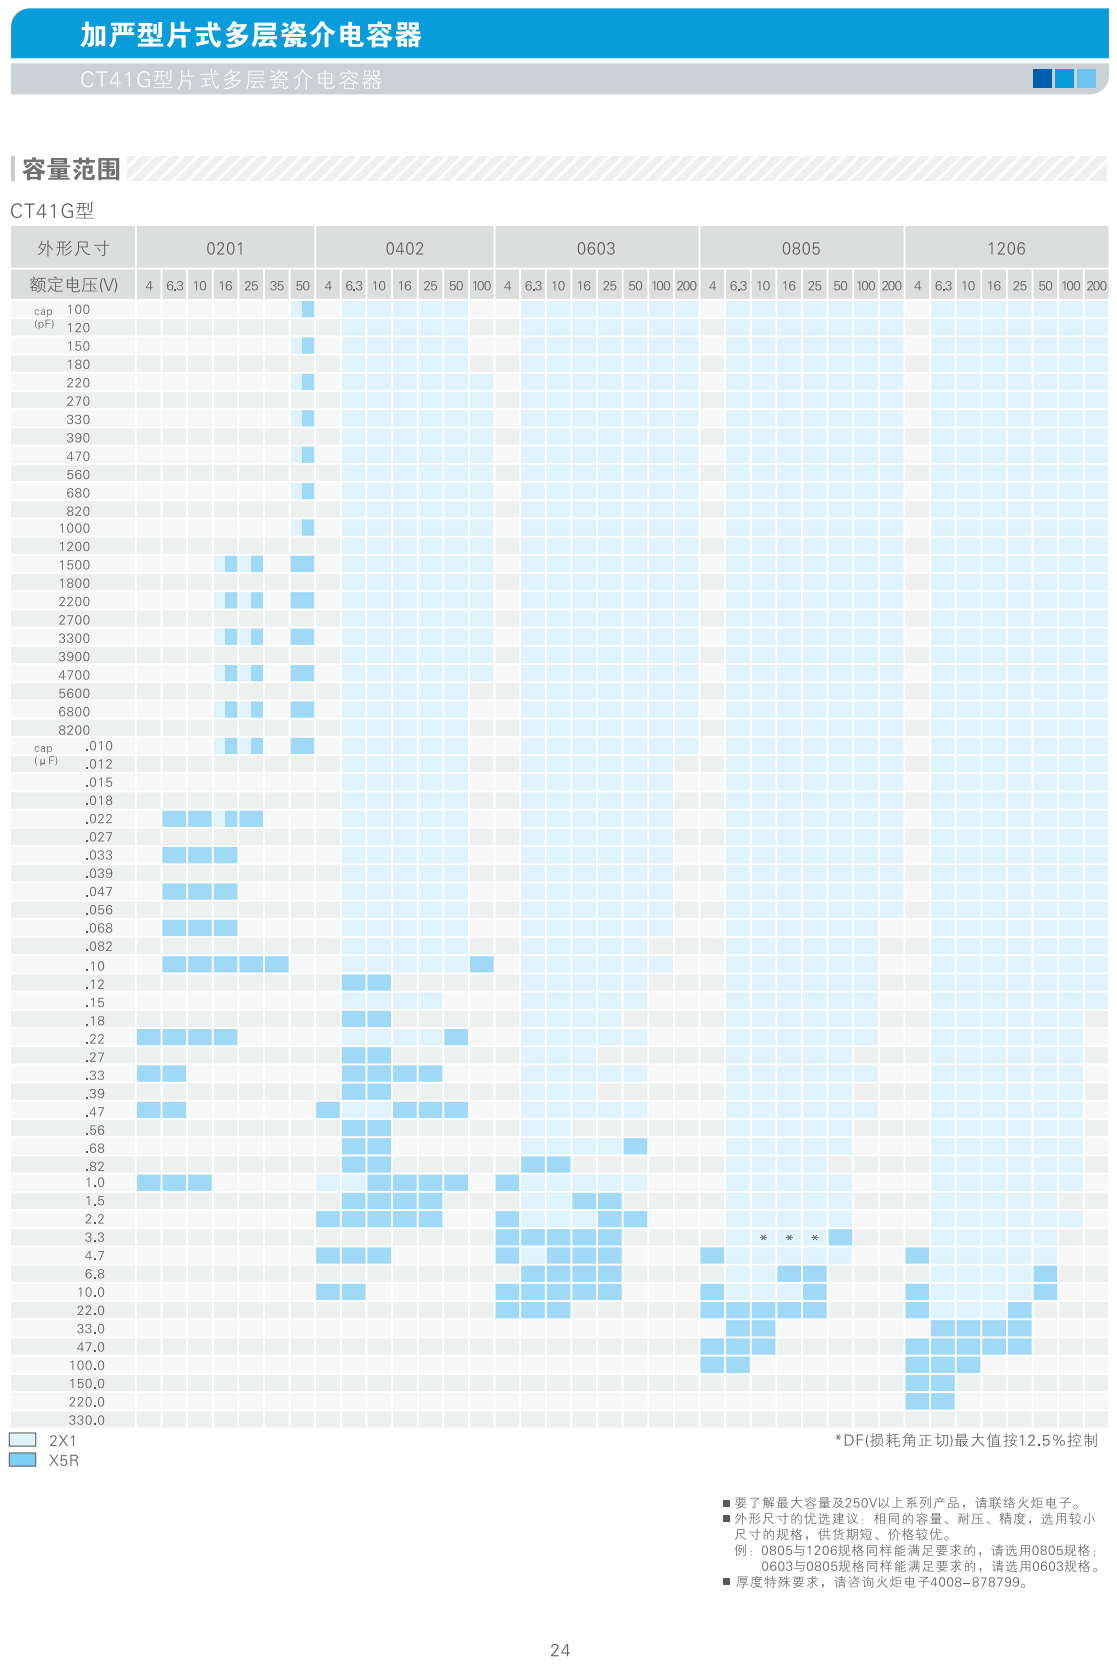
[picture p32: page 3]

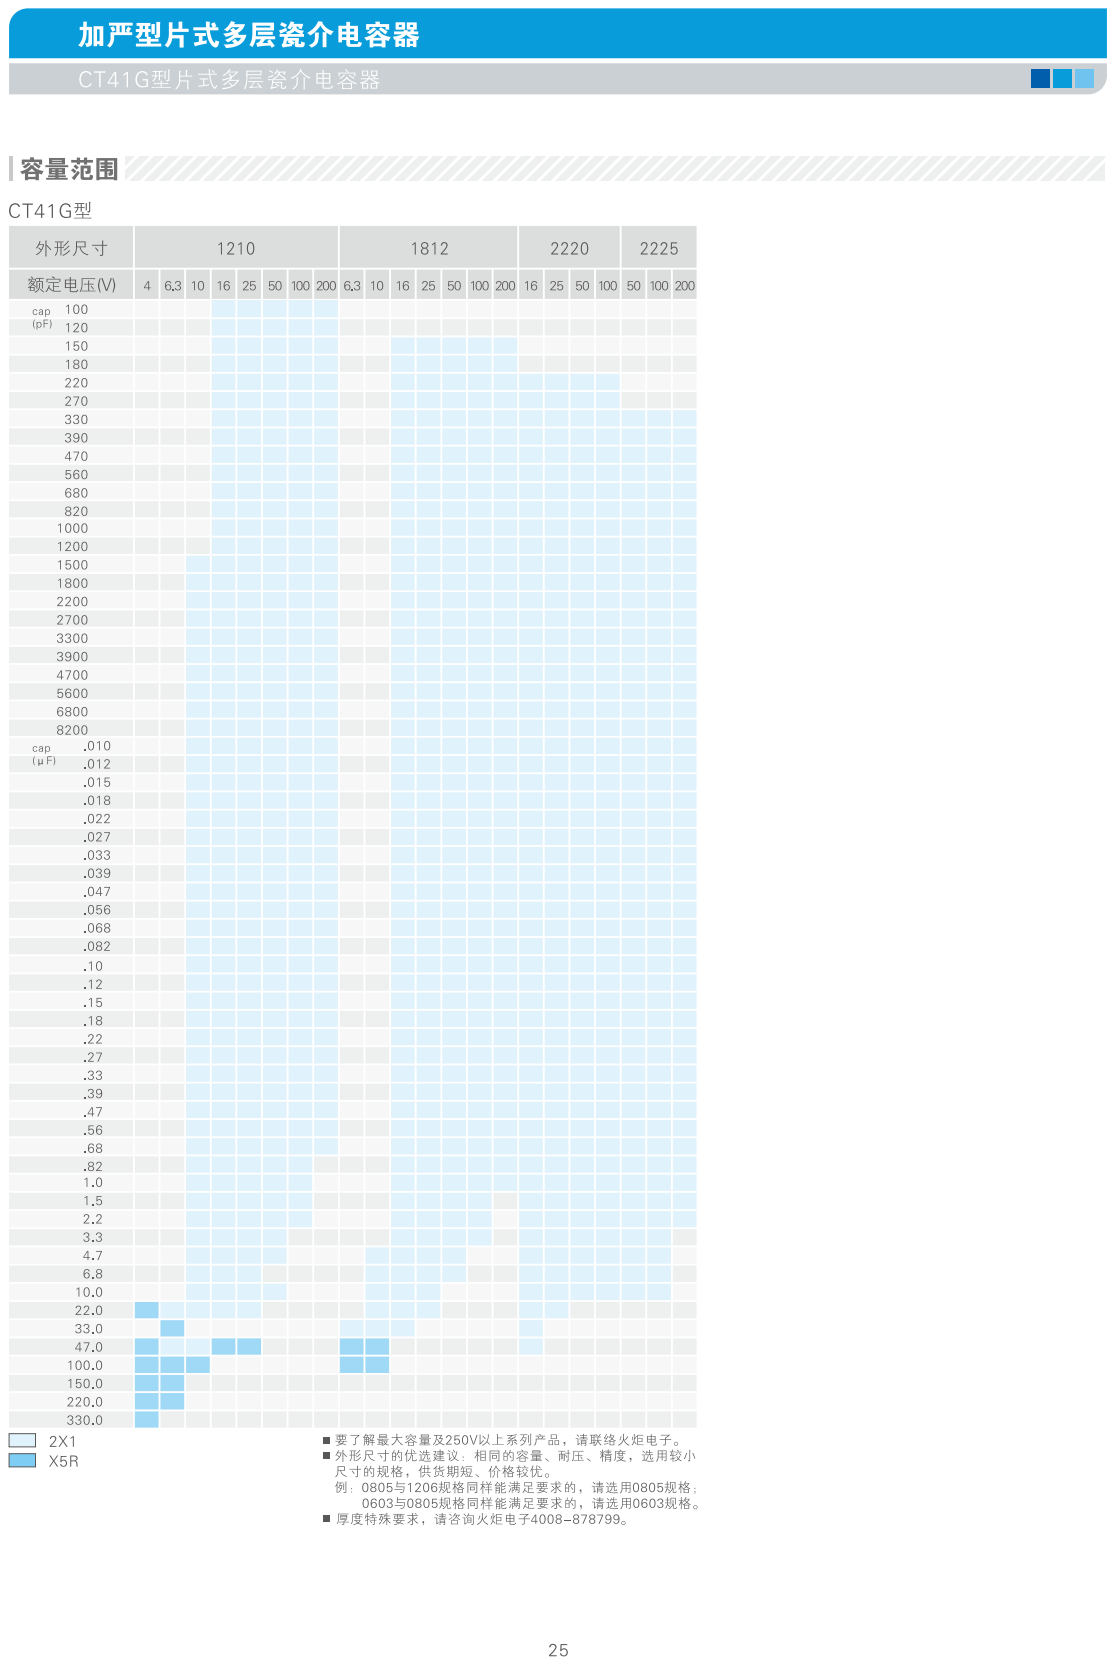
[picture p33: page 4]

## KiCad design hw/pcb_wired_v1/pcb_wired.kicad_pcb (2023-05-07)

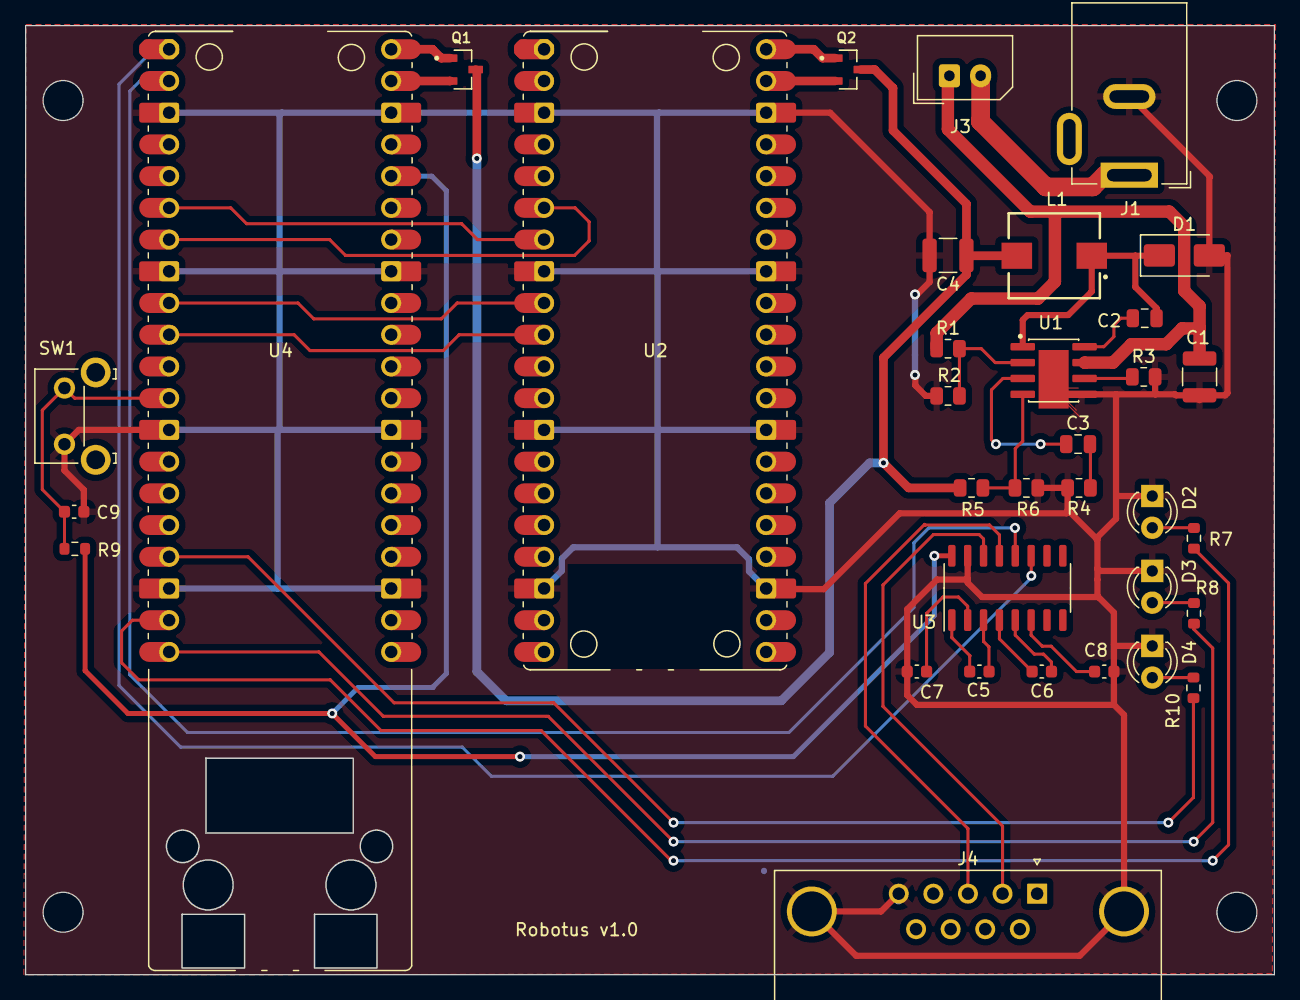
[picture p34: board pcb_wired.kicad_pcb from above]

Board: 2 copper layers, 100.0 x 76.0 mm, 34 parts (0 on the bottom side), 37 nets.

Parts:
C1: 10uF 50V; C_1210_3225Metric
C2: 0.1uF; C_0805_2012Metric
C3: 220pF; C_0805_2012Metric
C4: 22uF; C_1210_3225Metric
C5, C6, C7, C8: 100nF; C_0603_1608Metric
C9: 10nF; C_0603_1608Metric
D1: SS34; D_SMA
D2, D3, D4: LED; LED_D3.0mm
J1: Barrel_Jack_MountingPin; BarrelJack_GCT_DCJ200-10-A_Horizontal
J3: Conn_01x02; Molex_SPOX_5267-02A_1x02_P2.50mm_Vertical
J4: RS232; DSUB-9_Female_Horizontal_P2.77x2.84mm_EdgePinOffset7.70mm_H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
L1: 4.7uH; INDP7368X320_Inductor
Q1, Q2: DMG2305UX-7; SOT91P240X110-3N_DMG2305UX-7
R1: 100K; R_0805_2012Metric
R2: 24K9; R_0805_2012Metric
R3: 200K; R_0805_2012Metric
R4: 68K; R_0805_2012Metric
R5: 43K; R_0805_2012Metric
R6: 8K2; R_0805_2012Metric
R7, R8, R10: 120; R_0603_1608Metric
R9: 1K; R_0603_1608Metric
SW1: SW_Push; SW_SPST_Omron_B3F-315x_Angled
U1: MP1584EN; SOIC127P600X170-9N_MP1584EN
U2: Raspberry Pi Pico W; Raspberry_Pi_Pico_W_SMT_THT
U3: MAX3232; SO-16_3.9x9.9mm_P1.27mm
U4: W5500-EVB-Pico; W5500-EVB-Pico_SMT_THT

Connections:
+3.3V: R9.1, U3.16 (VCC), U4.36 (3V3)
+5V: C4.1, L1.2, Q1.3, Q2.3, R5.1
+24V: C1.1, J3.1, R1.1, U1.7 (VIN)
+24VP: J1.1, J3.2
BTN: C9.1, R9.2, SW1.2, U4.12 (GPIO9)
GND: C1.2, C4.2, C7.2, C8.2, C9.2, D1.2, D2.1 (K), D3.1 (K), D4.1 (K), J1.2, J4.0 (PAD), J4.5, R2.2, R3.2, R4.2, R6.2, SW1.1, U1.5 (GND), U2.3 (GND_1), U2.8 (GND_2), U2.13 (GND_3), U2.18 (GND_4), U2.23 (GND_5), U2.28 (GND_6), U2.33 (AGND), U2.38 (GND_7), U3.15 (GND), U4.3 (GND_1), U4.8 (GND_2), U4.13 (GND_3), U4.18 (GND_4), U4.23 (GND_5), U4.28 (GND_6), U4.33 (AGND), U4.38 (GND_7)
unnamed: C3.2, R4.1
unnamed: D2.2 (A), R7.1
unnamed: D3.2 (A), R8.1
unnamed: D4.2 (A), R10.1
unnamed: C2.1, U1.8 (BST)
unnamed: C3.1, U1.3 (COMP)
unnamed: R1.2, R2.1, U1.2 (EN)
unnamed: R5.2, R6.1, U1.4 (FB)
unnamed: R3.1, U1.6 (FREQ)
unnamed: C2.2, L1.1, U1.1 (SW)
unnamed: Q2.1, U2.40 (VBUS)
unnamed: Q2.2, U2.39 (VSYS)
unnamed: C5.1, U3.1 (C1+)
unnamed: C5.2, U3.3 (C1-)
unnamed: C6.1, U3.4 (C2+)
unnamed: C6.2, U3.5 (C2-)
unnamed: C7.1, U3.2 (VS+)
unnamed: C8.1, U3.6 (VS-)
unnamed: R10.2, U4.17 (GPIO13)
unnamed: R7.2, U4.19 (GPIO14)
unnamed: R8.2, U4.20 (GPIO15)
unnamed: Q1.1, U4.40 (VBUS)
unnamed: Q1.2, U4.39 (VSYS)
P6: U2.9 (GPIO6), U4.9 (GPIO6)
P7: U2.10 (GPIO7), U4.10 (GPIO7)
RS232_RX: J4.3, U3.13 (R1IN)
RS232_TX: J4.2, U3.14 (T1OUT)
UART0_RX: U3.12 (R1OUT), U4.2 (GPIO1)
UART0_TX: U3.11 (T1IN), U4.1 (GPIO0)
UART1_RX: U2.6 (GPIO4), U4.7 (GPIO5)
UART1_TX: U2.7 (GPIO5), U4.6 (GPIO4)

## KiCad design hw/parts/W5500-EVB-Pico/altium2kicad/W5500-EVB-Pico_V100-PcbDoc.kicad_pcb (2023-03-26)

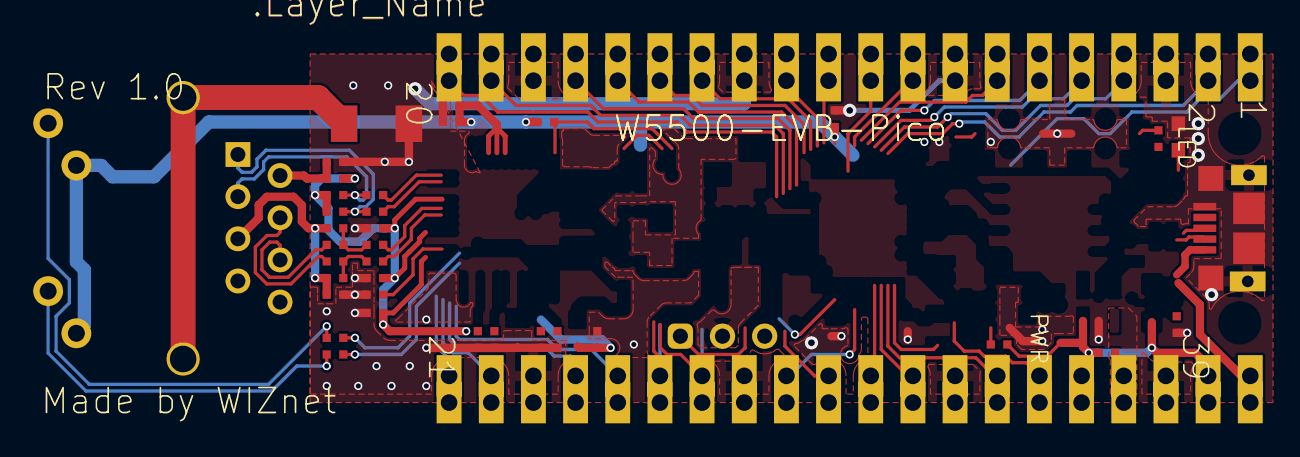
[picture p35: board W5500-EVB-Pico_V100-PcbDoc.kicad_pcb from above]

Board: 2 copper layers, 39 parts (0 on the bottom side), 18 nets.

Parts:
C12, C15, C16, C17, C18, C19, C20, C21, C22, C23, C28, C29, C30, C35, C36: Ceramic CAP 0402(1005); CAP-0402
C31: Ceramic CAP 1808(4520); CAP-1808
J1, J2: 2.54mm 1x20 Pin Header DIP; IDC-1X20
J3: 2.54mm 1x3 Pin Header DIP; IDC-1X3
LD2: LED-0603; LED-0603-GREEN
P1: Micro USB B Connector SMD; MICRO 5P B DBX 6.4
P2: J1B1211CCD; RJ45-J1B1211CCD
R3, R4, R5, R12, R15, R16, R17, R18, R19, R20, R21, R22, R26, R27, R28, R29, R30: RES-0402

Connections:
3V3: C12.2, C15.2, C16.2, J2.16, P2.10, P2.12, R12.2
3V3A: C17.2, C18.2, C19.2, C20.2, C21.2, C22.2, C23.2, R19.2, R20.2, R28.1
3V3_EN: J2.17, R3.2
CHGND: C31.2, P2.S1, P2.S2
GND: C12.1, C15.1, C16.1, C17.1, C18.1, C19.1, C20.1, C21.1, C22.1, C23.1, C28.1, C29.1, C30.1, C31.1, J1.3, J1.8, J1.13, J1.18, J2.3, J2.8, J2.13, J2.18, J3.2, LD2.2, P1.5, P1.6, P1.7, P1.8, P1.9, P1.10, P1.11, R4.1, R27.2
GPIO20: J2.6, R12.1
NetC28_2: C28.2, P2.2, R28.2
NetC30_2: C30.2, P2.5, R21.1, R22.1
NetC35_1: C35.1, R18.1, R22.2
NetC35_2: C35.2, P2.4
NetC36_1: C36.1, R17.1, R21.2
NetC36_2: C36.2, P2.6
NetP2_1: P2.1, R16.1, R19.1
NetP2_3: P2.3, R15.1, R20.1
NetP2_9: P2.9, R29.1
NetP2_11: P2.11, R30.1
VBUS: J2.20, P1.1
VSYS: J2.19, R3.1, R5.2

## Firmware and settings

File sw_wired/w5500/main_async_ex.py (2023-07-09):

'''
W5500 
'''
import machine
from machine import Pin
from machine import Timer
from machine import UART

import utime
from usocket import socket
import uselect
import gc

import network
import ujson
import mpyaes as aes
import usocket
import uasyncio

import coder
from led import *
from w5500 import w5x00_init
import utils

KEY = b'aD\xd8\x11e\xdcy`\t\xdc\xe4\xa7\x1f\x11\x94\x93'

BAUD_RATE = 9600
if BAUD_RATE == 9600:
    SERIAL1_TIMEOUT = 200 # ms
else:
    SERIAL1_TIMEOUT = 100 # ms

print('Starting W5500 script')
led_onoff(led, False)
led_onoff(yellow, False)
led_onoff(green, False)
led_onoff(red, False)

serial_running = False

def init_serial():
    uart0 = UART(0, tx=Pin(0), rx=Pin(1))
    uart0.init(baudrate=BAUD_RATE, bits=8, parity=None, stop=1, timeout=SERIAL1_TIMEOUT)

    return uart0

def do_serial(u0):
    global serial_running
    sm = u0.readline()
    if sm:
        try:
            sm = sm.decode('utf-8')
            sm = sm.strip()
            print(sm)
            cmd = sm[:7]
            print(f'cmd: {cmd}')
            print(f'sm[-7:]: {sm[-7:]}')
            if cmd=='CNF_REQ':
                json_settings = utils.load_json_settings()
                print('json_settings: ', json_settings)
                print('type(json_settings): ', type(json_settings))
                settings = ujson.dumps(json_settings)
                print(len(settings), ' bytes : ', settings)
                msg = bytes('CNF_JSN', 'utf-8') + bytes(settings, 'utf-8') + bytes('CNF_END\n', 'utf-8')
                u0.write(msg)
            elif cmd=='CNF_WRT' and sm[-7:]=='CNF_END':
                u0.deinit()
                u0 = None
                settings = sm[7:-7]
                print(f'Received settings: {settings}')
                utils.save_settings(settings)
                serial_running = False
                return
            else:
                print('Unknown command')
        except Exception as e:
            print(e)
        
    return

async def handler(reader, writer):
    b64 = await reader.readline()
    print('Data received from stream reader: ', b64)
    print('type(b64): ', type(b64))    
    
async def run_server_async(ip, port, key, u0):
    global serial_running
    conn = None
    server_sock = None
    u0 = None
    
    #tcp_reader, tcp_writer = await uasyncio.open_connection(ip, int(port))
    
    server = await uasyncio.start_server(handler, ip, int(port))
    async with server:
        await server.serve_forever()
        
    return

    while 1:
        b64 = await tcp_reader.readline()
        print('Data received from stream reader: ', b64)
        print('type(b64): ', type(b64))
        
        break
    
        if len(b64) <= 4:
            print('irregular data. Exit')
            break
        else:
            cmd, msg = b64[:4], b64[4:]
            cmd = cmd.decode('utf-8')
            print(f'cmd: {cmd}')

            if cmd == 'TEXT':
                print(f'msg: {msg}')
                IV = aes.generate_IV(16)
                cipher = aes.new(keyb, aes.MODE_CBC, IV)
                msg = cipher.encrypt(msg)
                iv_c = IV + msg
                print('IV: ')
                print(IV)
                print('msg: ')
                print(msg)
                
                tcp_writer.write(iv_c)
                await tcp_writer.drain()
                print('writer written: ', iv_c)
                
            elif cmd == 'CIPH':
                print(f'msg: {msg}')
                IV, msg = msg[:16], msg[16:]
                print('IV: ')
                print(IV)
                print('msg: ')
                print(msg)
                msga = bytearray(msg)
                cipher = aes.new(keyb, aes.MODE_CBC, IV)
                plaintext = cipher.decrypt(msga)
                conn.send(plaintext)

    if conn:
        conn.close()
    if server_sock:
        server_sock.close()
    if u0:
        u0.deinit()

    if tcp_reader:
        tcp_reader.close()
    
    if tcp_writer:
        tcp_writer.close()

    utime.sleep(2)

    #print('Resetting the machine')
    #machine.reset()
    return

    
def run_server_single(ip, port, key, u0):
    global serial_running  # reset button flag

    server_sock = socket()
    server_sock.bind((ip, int(port)))
    
    print('Listening on socket: ', server_sock)
    server_sock.listen(4)

    if len(key) > len(coder.KEY):
        key = key[:len(coder.KEY)]
    keyb = key.encode()
    keyb = keyb + coder.KEY[len(keyb):]

    p1 = uselect.poll()
    p1.register(server_sock, uselect.POLLIN)

    print('Waiting for connection...')
    conn = None

    time_start = utime.ticks_ms()

    while serial_running:
        res = p1.poll(100)
        if not res:
            do_serial(u0)
            print('no client at server_sock')
            time_now = utime.ticks_ms()
            runtime = utime.ticks_diff(time_now, time_start)
            if runtime > 25000:
                print(runtime)
                gc.collect()
                time_start = time_now
            continue
        print('client available')
        conn, addr = server_sock.accept()
        print('Connected by ', conn, ' from ', addr)
        break

    if not serial_running:
        if conn:
            conn.close()
        server_sock.close()
        return
        
    poller = uselect.poll()
    poller.register(conn, uselect.POLLIN)
    
    time_start = utime.ticks_ms()

    while serial_running:
        res = poller.poll(100)
        if not res:
            do_serial(u0)
            print('no data from conn')
            time_now = utime.ticks_ms()
            runtime = utime.ticks_diff(time_now, time_start)
            if runtime > 25000:
                print(runtime)
                gc.collect()
                time_start = time_now
            continue

        print('data arrived at conn')

        b64 = conn.recv(128)
        print('data received: ', b64)
        print('type(b64): ', type(b64))
        
        if len(b64) <= 4:
            print('irregular data. Exit')
            break
        else:
            cmd, msg = b64[:4], b64[4:]
            cmd = cmd.decode('utf-8')
            print(f'cmd: {cmd}')

            if cmd == 'TEXT':
                print(f'msg: {msg}')
                IV = aes.generate_IV(16)
                cipher = aes.new(keyb, aes.MODE_CBC, IV)
                msg = cipher.encrypt(msg)
                iv_c = IV + msg
                print('IV: ')
                print(IV)
                print('msg: ')
                print(msg)
                conn.send(iv_c)
            elif cmd == 'CIPH':
                print(f'msg: {msg}')
                IV, msg = msg[:16], msg[16:]
                print('IV: ')
                print(IV)
                print('msg: ')
                print(msg)
                msga = bytearray(msg)
                cipher = aes.new(keyb, aes.MODE_CBC, IV)
                plaintext = cipher.decrypt(msga)
                conn.send(plaintext)

    if conn:
        conn.close()
    if server_sock:
        server_sock.close()
    if u0:
        u0.deinit()

    utime.sleep(2)

    #print('Resetting the machine')
    #machine.reset()
    return

def main_single():
    global serial_running

    led_onoff(red, True)

    json_settings = utils.load_json_settings()
    print(json_settings)

    serial_running = True
    u0 = init_serial()
    
    if json_settings['dhcp']:
        net_info = w5x00_init(None)
    else:
        net_info = w5x00_init((json_settings['ip'], json_settings['subnet'], json_settings['gateway']))

    if net_info[0]:
        print('IP assigned: ', net_info[0])
        json_settings['ip'] = net_info[0]
        json_settings['subnet'] = net_info[1]
        json_settings['gateway'] = net_info[2]
        utils.save_settings(ujson.dumps(json_settings))
        led_onoff(green, True)

        run_server_single(json_settings['ip'], json_settings['port'], json_settings['key'], u0)
    else:
        print('No IP assigned')
        led_onoff(yellow, True)
        led_onoff(green, False)


    led_onoff(green, False)
    print("Waiting for 2 sec")
    utime.sleep(2)
    print("Exit from main function")

    machine.reset()

async def main_async():
    global serial_running

    led_onoff(red, True)

    json_settings = utils.load_json_settings()
    print(json_settings)

    u0 = init_serial()
    serial_running = True
    
    if json_settings['dhcp']:
        net_info = w5x00_init(None)
    else:
        net_info = w5x00_init((json_settings['ip'], json_settings['subnet'], json_settings['gateway']))

    if net_info[0]:
        print('IP assigned: ', net_info[0])
        json_settings['ip'] = net_info[0]
        json_settings['subnet'] = net_info[1]
        json_settings['gateway'] = net_info[2]
        utils.save_settings(ujson.dumps(json_settings))
        led_onoff(green, True)

        await run_server_async(json_settings['ip'], json_settings['port'], json_settings['key'], u0)
    else:
        print('No IP assigned')
        led_onoff(yellow, True)
        led_onoff(green, False)

    return

    led_onoff(green, False)
    print("Waiting for 2 sec")
    utime.sleep(2)
    print("Exit from main function")

    machine.reset()


if __name__ == '__main__':
    uasyncio.run(main_async())

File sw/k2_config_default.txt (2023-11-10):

comm:/dev/ttyUSB0
speed:9600
parity:N
data:8
stop:1
ip:192.168.2.209
gateway:192.168.2.1
subnet:255.255.255.0
peer_ip:192.168.0.6
host_ip:192.168.0.2192.168.0.2192.168.2.88
host_port:8503
channel:1
key:12345678

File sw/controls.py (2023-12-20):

import flet as ft
from pprint import pp

import comm
import w5500.constants as c
import options
from options import OS

ENC_COLUMN_WIDTH = 1000
LEFT_TITLE_WIDTH = 140
MID_TITLE_WIDTH = 60 

TITLE_ALIGN = ft.TextAlign.CENTER
MID_TITLE_ALIGN = ft.TextAlign.END

TITLE_WEIGHT = ft.FontWeight.BOLD
TITLE_SIZE = 18

LONG_FIELD = 180
SHORT_FIELD = 100
MID_FIELD = 120
INPUT_HINT = "전송할 데이터를 입력하세요"

GROUP_WIDTH_MARGIN = 50
GROUP_WIDTH = LEFT_TITLE_WIDTH + LONG_FIELD + GROUP_WIDTH_MARGIN
GROUP_TITLE_HEIGHT = 50
GROUP_SPACE=4

BUTTON_HEIGHT = 40
BUTTON_BAR_HEIGHT = 60
GROUP_HEIGHT = 480
WINC_WINDOW_WIDTH = GROUP_WIDTH*3+GROUP_SPACE*4 + 10
WINC_WINDOW_HEIGHT = GROUP_HEIGHT + 85 

g_page = None
info_text = ft.Text('Dropdown focus count', width=LEFT_TITLE_WIDTH, text_align=TITLE_ALIGN, weight=TITLE_WEIGHT)

def on_portlist_focus(e):
    ports = comm.serial_ports()
    e.control.options.clear()
    if ports:
        for port in ports:
            e.control.options.append(ft.dropdown.Option(port))
    e.control.page.update()

def read_from_device(e):
    pass

def read_and_apply_options():
    OS.apply_settings(options.load_settings())

def init():
    OS.get(c.HOST_IP).set_value(comm.find_host_ip())
    read_and_apply_options()

class OptionRow(ft.Row):
    def __init__(self, label, control, options_tuple):
        self.option_label = ft.Text(label, width=LEFT_TITLE_WIDTH, text_align=TITLE_ALIGN, weight=TITLE_WEIGHT)
        if control == ft.TextField:
            self.option_control = ft.TextField(width=LONG_FIELD, bgcolor=ft.colors.WHITE70)
        elif control == ft.Dropdown:
            _dd = ft.Dropdown(width=LONG_FIELD, bgcolor=ft.colors.WHITE70,
                                    value=options_tuple[1][options_tuple[0]],
                                    options=[ft.dropdown.Option(option) for option in options_tuple[1]],
                                )
            self.option_control = ft.Container(_dd, width=LONG_FIELD, bgcolor=ft.colors.WHITE70)
        elif control == ft.RadioGroup:
            self.option_control = ft.RadioGroup(value=options_tuple[0], content = ft.Row([ft.Radio(value=idx, label=option) for idx, option in enumerate(options_tuple[1])]))
        else:
            assert False, f"Unknown control type: {control}"
        super().__init__(spacing=5, width=ENC_COLUMN_WIDTH, alignment=ft.MainAxisAlignment.START,
                    controls=[self.option_label, self.option_control])
    
    def get_value(self):
        return self.controls[1].value

    def set_value(self, value):
        self.controls[1].value = value

class OptionGroup(ft.Container):
    def __init__(self, title, options):
        self.group_title = ft.Container( 
                                ft.Text(title, weight=TITLE_WEIGHT, size=TITLE_SIZE), 
                                alignment=ft.alignment.center, 
                                bgcolor=ft.colors.BLUE_200, 
                                width=GROUP_WIDTH, 
                                height=GROUP_TITLE_HEIGHT)
        self.options = options
        content = ft.Column(
                        scroll=ft.ScrollMode.HIDDEN, 
                        expand=True, 
                        alignment=ft.MainAxisAlignment.START, 
                        controls=[self.group_title]+self.options, 
                        width=GROUP_WIDTH,
                        height=GROUP_HEIGHT,)
        super().__init__(content=content, width=GROUP_WIDTH, height=GROUP_HEIGHT, bgcolor=ft.colors.BLUE_GREY_100)

button_row = ft.Container( bgcolor=ft.colors.BLUE_GREY_100, width=GROUP_WIDTH*3+GROUP_SPACE*2, height=BUTTON_BAR_HEIGHT,
                content=ft.Row(spacing = 50, width = WINC_WINDOW_WIDTH, height = BUTTON_BAR_HEIGHT, alignment=ft.MainAxisAlignment.CENTER,
                            controls = [
                                ft.FilledButton("단말에서 설정 읽어오기", on_click=read_from_device, width=200, height=BUTTON_HEIGHT,
                                        style=ft.ButtonStyle(shape={ft.MaterialState.DEFAULT: ft.RoundedRectangleBorder(radius=2),})),
                                ft.FilledButton("단말에 설정 저장", on_click=read_from_device, width=200, height=BUTTON_HEIGHT, 
                                        style=ft.ButtonStyle(shape={ft.MaterialState.DEFAULT: ft.RoundedRectangleBorder(radius=2),})),
                            ]))

or_serial_port_list = OptionRow("시리얼 포트 목록:", ft.Dropdown, (0, comm.serial_ports()))
or_serial_port_list.option_control.on_focus = on_portlist_focus

OS.add(c.CHANNEL, OptionRow("통신채널:", ft.RadioGroup, c.CHANNEL_OPTIONS))
OS.add(c.HOST_IP, OptionRow("호스트 IP:", ft.TextField, []))
OS.add(c.HOST_PORT, OptionRow("호스트 포트:", ft.TextField, []))

OS.add(c.SERIAL_PORT, OptionRow("시리얼 포트:", ft.TextField, []))
OS.add(c.SPEED, OptionRow("시리얼 속도:", ft.Dropdown, c.SPEED_OPTIONS))
OS.add(c.PARITY, OptionRow("패리티 비트:", ft.Dropdown, c.PARITY_OPTIONS))
OS.add(c.DATA, OptionRow("데이터 비트:", ft.Dropdown, c.DATA_OPTIONS))
OS.add(c.STOP, OptionRow("스톱 비트:", ft.Dropdown, c.STOP_OPTIONS))

OS.add(c.MY_IP, OptionRow("단말 IP:", ft.TextField, []))
OS.add(c.GATEWAY, OptionRow("게이트웨이:", ft.TextField, []))
OS.add(c.SUBNET, OptionRow("서브넷마스크:", ft.TextField, []))
OS.add(c.PEER_IP, OptionRow("상대 단말 IP:", ft.TextField, []))
OS.add(c.KEY, OptionRow("암호키:", ft.TextField, []))

og_host = OptionGroup("호스트 설정", 
            [OS.get(c.CHANNEL), OS.get(c.HOST_IP), OS.get(c.HOST_PORT)])
og_serial = OptionGroup("시리얼 통신 설정", 
            [OS.get(c.SERIAL_PORT), or_serial_port_list, OS.get(c.SPEED), OS.get(c.PARITY), OS.get(c.DATA), OS.get(c.STOP)])
og_device = OptionGroup("단말 설정", 
            [OS.get(c.MY_IP), OS.get(c.GATEWAY), OS.get(c.SUBNET), OS.get(c.PEER_IP), OS.get(c.KEY)])

def close_dlg(e):
    alert_dlg.open = False
    e.control.page.update()

def validate_required_text_field(e):
        if e.control.value == "":
            e.control.error_text = "The field is required"
            e.control.update()

alert_dlg = ft.AlertDialog(
        modal=True,
        title=ft.Text("오류"),
        content=ft.Text("감사합니다 "),
        actions=[
            ft.TextButton("OK", on_click=close_dlg),
        ],
        actions_alignment=ft.MainAxisAlignment.CENTER,
        on_dismiss=lambda e: print("Modal dialog dismissed!"),
    )

def get_settings():
    return {
        'dirty': True,
        'chan': channel.value, 
        'host_ip': host_ip.value,
        'host_port': host_port.value,
        'device_ip': device_ip.value,
        'serial_port': serial_port.value,
        'serial_speed': serial_speed.value,
        'parity': parity.value,
        'data_size': data_size.value,
        'stopbit': stopbit.value
    }

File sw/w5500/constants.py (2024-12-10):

CH_TCP = 1      # channel to host
CH_SERIAL = 0

PEER_PORT = 8502
ENCRYPT_PORT = 2004

PARITY_NONE = 'N'
PARITY_EVEN = 0
PARITY_ODD = 1

CHANNEL_OPTIONS = (1, ['Serial', 'TCP'])
PARITY_OPTIONS = (0, [PARITY_NONE, PARITY_EVEN, PARITY_ODD])
DATA_OPTIONS = (1, [7, 8])
STOP_OPTIONS = (0, [1, 2])
SPEED_OPTIONS = (0, [9600, 19200, 38400])
DEFAULT_DEVICE_ID = 999

DEVICE_ID = 'id'
SERIAL_PORT = 'comm'
MY_IP = 'ip'
CONFIG = 'config'
GATEWAY = 'gateway'
SUBNET = 'subnet'
PEER_IP = 'peer_ip'
HOST_IP = 'host_ip'
HOST_PORT = 'host_port'
SPEED = 'speed'
PARITY = 'parity'
DATA = 'data'
STOP = 'stop'
CHANNEL = 'channel'
KEY = 'key'

DEFAUlT_SETTINGS = {
    #DEVICE_ID : DEFAULT_DEVICE_ID, # device id shouldn't be configured by the user
    MY_IP : '192.168.2.10',
    #CONFIG : 0,  # config mode is not used any more
    GATEWAY : '192.168.2.1',
    SUBNET : '255.255.255.0',
    PEER_IP : '192.168.2.9',
    HOST_IP : '192.168.2.88',
    HOST_PORT : 2004,
    SPEED : 9600,
    PARITY : 'N',   #N, E, O
    DATA : 8,
    STOP : 1,
    CHANNEL : CH_TCP, # 1=tcp, 0=serial
    KEY:'12345678'
}

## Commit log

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2023-02-28 pico-serial/main.py에서 불필요한 부분 삭제
2023-03-19 MOSFET for Pico Power Switching
2023-03-19 switching regulator for buck converter
    [MP1584EN.step]
2023-03-19 inductor for power circuit
    [RLF7030T-4R7M3R4.step]
2023-03-19 Schottky rectifier for buck converter
    [SS34.step]
2023-03-22 add kicad project
    [pcb.kicad_pcb, pcb.kicad_sch]
2023-03-22 add W5500-Evb-Pico kicad project
    [0.dat.step, 1.dat.step, 10.dat.step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]
2023-03-22 rename inductor
    [RLF7030T-4R7M3R4.step]
2023-03-22 add MP1584EN files
    [Buck 3A MP1584.GBL, Buck 3A MP1584.GBS, Buck 3A MP1584.GKO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]
2023-03-26 w5500-evb-pico footprint
    [W5500-EVB-Pico_V100-PcbDoc.kicad_pcb, pcb.kicad_sch, wrlshapes.kicad_pcb]
2023-03-26 MP1584EN symbol and footprints
2023-03-27 kicad data & hw parts info
    [pcb.kicad_sch]
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2023-03-27 kicad sch
    [pcb.kicad_sch]
2023-03-29 schematic v1 completed
    [DMG2305UX-7.step, pcb.kicad_sch]
2023-04-14 old pcb backups removed
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2023-04-14 bom xml for JLCPCB 1st order
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2023-04-17 common read/write main.py for pico-w
2023-04-17 socket server client examples
2023-04-25 case base for fitting pcb into the design
    [case_base.stl]
2023-04-25 latest kicad project files
    [pcb-B_Cu.gbr, pcb-B_Mask.gbr, pcb-B_Paste.gbr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]
2023-04-26 2023.4 최신 회로 및 PCB
2023-04-26 software for pcb v1
2023-04-26 software for pcb v2
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2023-04-28 소자 이름 깨지는 거 수정
2023-04-28 소자 파일 이름 깨지는 문제 수정
2023-04-29 pico-w micropython release v1.20.0 2023.04.26
2023-05-06 code for pcb v2
2023-05-06 new case design
    [winners-case-v2.FCStd]
2023-05-06 old pcb removed
    [pcb-B_Cu.gbr, pcb-B_Mask.gbr, pcb-B_Paste.gbr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]
2023-05-06 old pcb folder renamed
    [pcb.kicad_pcb, pcb.kicad_sch]
2023-05-06 2023.4 delivery from interboard
    [pcb-B_Cu.gbr, pcb-B_Mask.gbr, pcb-B_Paste.gbr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]
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2023-05-06 pcb v6 a new copy for three LEDs
    [pcb-B_Cu.gbr, pcb-B_Mask.gbr, pcb-B_Paste.gbr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]
2023-05-06 sch update
    [pcb.kicad_sch]
2023-05-07 pcb update
    [pcb.kicad_pcb, pcb.kicad_sch]
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2023-05-07 power ic MP1584EN library footprint update
2023-05-07 sch & pcb update
    [pcb.kicad_pcb, pcb.kicad_sch]
2023-05-08 gerber sent to jlcpcb
    [pcb-B_Cu.gbl, pcb-B_Cu.gbr, pcb-B_Mask.gbs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]
2023-05-08 create spreadsheet
    [winners-case-v2.FCStd]
2023-05-08 pcb v6.2 submitted to jlcpcb
    [pcb-B_Cu.gbl, pcb-B_Mask.gbs, pcb-B_Paste.gbp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]
2023-05-08 freecad pcb + w550 + db9
    [winners-case-v2.FCStd]
2023-05-09 free cad case design
    [winners-case-v2.FCStd]
2023-05-10 base sheet finished
    [winners-case-v2.FCStd]
2023-05-10 freecad backup
    [winners-case-v2.1.FCStd]
2023-05-11 export to dxf for test
    [base.dxf]
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2023-05-13 din rail holes, tech draw pages
    [winners-case-v2-front.FCStd]
2023-05-13 techdraw pages to dxf
    [base.dxf, top.dxf, whole.dxf]
2023-05-14 right view dxf
    [right_view.dxf]
2023-05-14 dxf update
    [top.dxf, whole.dxf]
2023-05-14 font for silk printing
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2023-05-14 hole for push button
    [winners-case-v2-front.FCStd]
2023-05-14 freecad update
    [winners-case-v2-front.FCStd]
2023-05-14 dxf files
    [base.dxf, base_left_right.dxf, case_2023.5.15-1-autocad.dwg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]
2023-05-14 device mart 주문
    [case_2023.5.15-1-autocad.dwg]
2023-05-17 add case image and schematics
2023-05-21 Update README.md with schematics
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2023-05-25 3차 케이스 의뢰
    [case_2023.5.25-1-autocad.dwg]
2023-05-29 case USB1 -> USB11 변경
    [case_2023.5.25-1-autocad.dwg, case_2023.5.29-1-autocad.dwg]
2023-06-04 5.26 case order update
    [case_2023.5.30-1-autocad.dwg]
2023-06-06 pico-w 제거 회로도
    [pcb_wired.kicad_pcb, pcb_wired.kicad_sch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]
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2023-06-06 usb cover stl
    [usb_cover.stl, usb_cover_4.stl]
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2023-06-08 w5500 초기화 함수 수정
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2023-06-11 json 오류 수정, refactoring
    [utils.py]
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2023-06-18 add PC program for KC test
    [k2_config.txt]
2023-06-18 config for KC test program
    [k2_config.txt]
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2023-06-28 baud=9600, w5500_init() 리턴값 처리, 사용하지 않는 함수 삭제
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2023-06-28 w5500 ip assign 대기 시간 20초 -> 10초
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2023-06-28 프로그램 시작 시 dhcp event 처리, 프로그램 버전 표시
2023-06-28 /tty/USB0 -> COM7
    [k2_config.txt]
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2023-06-29 단말에서 읽어온 설정을 UI에 적용 시 문제점 수정 중
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2023-07-01 w5500 모듈에 맞게 UART 변경, uart readline()을 위해 \n 추가
2023-07-01 pyb의 heartbeat()을 w5500 모듈에 맞게 수정
    [async_server.py]
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2023-07-03 KC인증 ESD 이슈 대응을 위한 w5500-evb-pico PCB, 회로도 캡쳐
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2023-07-09 serial 예제 수정
2023-10-15 kc인증툴 k2.py -> kc2.py로 변경, 동일 파일로 사용자용 툴 epc.py 생성
2023-10-16 option 추가, ui layout, options 별도 파일로 변경
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2023-10-17 make a new function for fix key length and encode the key
    [coder.py, main.py]
2023-10-18 correct default settings to include all fields
    [utils.py]
2023-10-18 print memory in garbage_collect(), keyb -> fixed_binary_key
    [main.py]
2023-10-18 PC 클라이언트 백업 epc -> epc_2023.10.19
    [k2_config.txt]
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2023-10-18 New source tree to include PC client and W5500 code
    [k2_config.txt]
2023-10-18 move old code into /backup
    [k2_config.txt]
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2023-10-19 socket 예제 수정
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2023-10-21 serial로 암호화 요청 실패하는 소스
    [k2_config.txt, k2_config_default.txt]
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2023-11-08 use sleep_ms()
    [k2_config.txt]
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2023-11-09 설정에 따라 필요할 때만 text port 트래픽 확인
2023-11-10 tcp socket receive fix
    [main.py]
2023-11-10 remove DHCP
    [k2_config.txt, k2_config_default.txt]
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2023-11-14 MicroPython 최신 펌웨어에 Wiznet TCP/IP 스택 올린 펌웨어(2023.10.12)
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2023-11-25 use blocking socket for send() inside stream handler
2023-12-02 hardware changes
    [winners-case-v2-3d.FCStd]
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2023-12-04 rm k2_config.txt
    [k2_config.txt]
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2023-12-04 fix relay function
2023-12-06 on fixing serial handler to add relay function
    [main.py]
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2023-12-07 remove backups
    [k2_config.txt]
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2023-12-08 simulate serial msg relay on docker device image
2023-12-08 fix tcp relay logic
    [main.py]
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2023-12-13 fix a logic error and wrong key names in web settings
    [utils.py]
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2023-12-17 device id & use global settings for web
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2023-12-19 call led_state_reset() before reset
2023-12-19 call led_state_reset() before reset, refactor comments
    [main.py]
2023-12-19 led state for error cases
    [main.py]
2023-12-19 부팅 중 IP 할당 시도 10초 -> 20초
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2024-11-10 prevent OSError: [Errno 98] Address already in use
    [socket_client.py, socket_server.py]
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2024-12-09 switch handle_crypto/text, reset on error, catch exception on stream read/write
    [main.py]
2024-12-09 fix serial handler apply
    [main.py]
2024-12-10 chagne port names in order to avoid confusion
    [constants.py, main.py]
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

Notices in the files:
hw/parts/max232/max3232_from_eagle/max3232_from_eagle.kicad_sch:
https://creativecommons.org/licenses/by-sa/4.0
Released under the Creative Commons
